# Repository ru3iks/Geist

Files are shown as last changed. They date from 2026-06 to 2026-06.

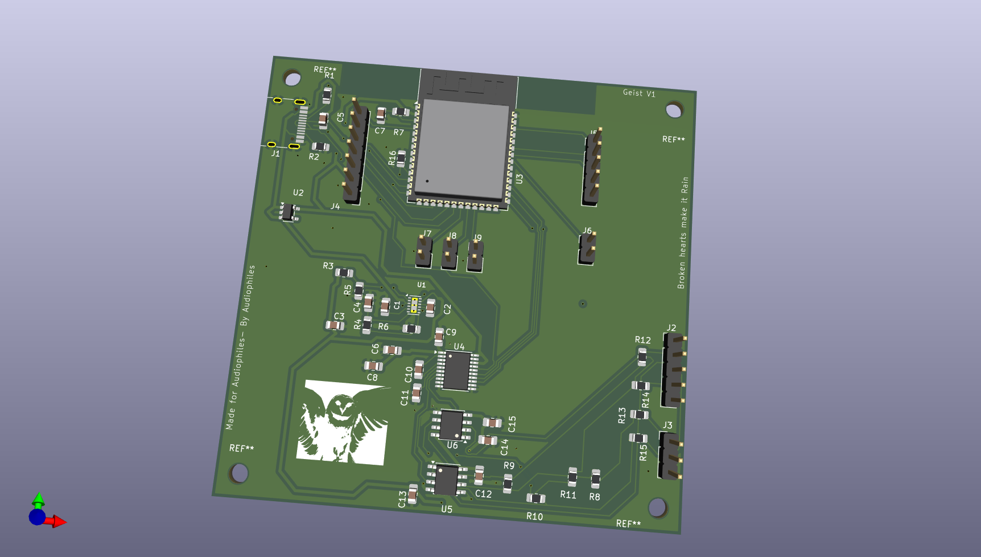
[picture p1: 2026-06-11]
Geist.png

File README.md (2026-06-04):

<div align="center">

# GEIST

**A reference-grade balanced USB DAC, real-time DSP engine, and tactile media controller — designed and built from scratch.**

`ESP32-S3` · `PCM5102A` · `OPA1656` · `Rust` · `Tauri`

---

*24-bit · 96kHz · Balanced 4.4mm Pentaconn · 10-Band Parametric EQ · FFT Visualizer*

</div>

---

## What is Geist?

Geist is an open-source USB audio device that I designed from the ground up — the circuit, the PCB, the firmware, and the companion app. It plugs into a computer over USB-C and serves three functions simultaneously:

1. **Reference-Grade USB DAC** — Enumerates as a class-compliant USB Audio device (UAC1). Receives lossless 24-bit/96kHz audio, converts it through a hardware DAC, and drives headphones through a true balanced amplifier stage.

2. **Real-Time DSP Engine** — A 10-band parametric EQ processes audio in real-time on the ESP32-S3's vector DSP unit. An FFT spectrum visualizer renders live on the onboard display.

3. **Tactile Media Controller** — Physical rotary encoder, mechanical buttons, and a toggle switch send HID commands back to the PC for volume and playback control. No drivers needed.

The companion desktop app (built in Rust + Tauri) pushes track metadata and album art to the device, provides a graphical EQ editor, and displays real-time audio analysis.

> This project was built as a 2nd year B.Tech ECE student at Manipal Institute of Technology. Every part of it — analog circuit design, mixed-signal PCB layout, embedded Rust firmware, and desktop application — was learned and implemented from scratch.

---

## Hardware Architecture

### The Signal Chain

```
  USB-C ──► AP2112K (3.3V LDO) ──► ESP32-S3 ──► PCM5102A DAC ──► 2× OPA1656 ──► Headphones
       └──► LM27762 (±4.5V Charge Pump) ─────────────────────────────┘
```

Every component was selected to serve a specific role in the audio path:

| Block | Component | Role |
|---|---|---|
| **Power (Digital)** | AP2112K-3.3 | LDO regulator — steps 5V USB to clean 3.3V for all digital logic |
| **Power (Analog)** | LM27762 | Bipolar charge pump — generates ±4.5V dual rails for the op-amps |
| **Digital Brain** | ESP32-S3-WROOM-1 | Dual-core 240MHz processor — USB audio streaming, DSP, UI control |
| **DAC** | PCM5102A | 32-bit delta-sigma DAC — converts I2S digital audio to analog |
| **Amplifiers** | 2× OPA1656 | Ultra-low-noise dual op-amps — buffers and creates balanced output |
| **Display** | ST7789 (240×240) | SPI LCD — track info or FFT visualizer |
| **Input** | Alps EC11 + 3 push buttons + SPDT toggle | Volume/nav encoder, media keys, mode switch |
| **Output** | 4.4mm Pentaconn + 3.5mm TRS | True balanced and single-ended headphone outputs |

### The Life of an Audio Sample

This table traces a single sample from the moment it leaves the PC to the moment it moves air:

```
Step   Location                  Signal State                        Domain
─────────────────────────────────────────────────────────────────────────────
 1     PC audio engine           24-bit integer: 0x3FFFFF            Software
 2     USB cable (D+/D-)         NRZI-encoded differential packet    Digital
 3     ESP32 USB DMA buffer      Bytes in RAM                        Digital
 4     ESP32 I2S peripheral      Serial bitstream at 3.072 MHz       Digital (3.3V)
 5     PCM5102A delta-sigma      1-bit stream at 6.144 MHz           Digital
 6     PCM5102A OUTL pin         +2.05V (audio + 1.55V DC bias)      Analog
 7     OPA1656 buffer output     +2.05V → OUT_L+ (hot phase)         Analog
 8     OPA1656 inverter output   −0.50V → OUT_L− (cold phase)        Analog
 9     After 10Ω resistors       +2.04V / −0.49V                     Analog
 10    Headphone driver          ΔV = 2.53V differential → sound     Acoustic
```

### Why Balanced?

A balanced signal carries audio on two wires moving in opposite directions. Any noise that couples into the cable appears equally on both wires and is cancelled by subtraction at the receiver:

```
Single-Ended:                      Balanced:
Signal ── ╱╲╱~~╲╱╲ ── +V+noise     HOT  ── ╱╲╱~~╲╱╲ ── +V+noise
Ground ── ──────── ── 0V            COLD ── ╲╱╲~~╱╲╱ ── −V+noise

Amp sees: signal + noise            Amp subtracts: (+V+noise) − (−V+noise)
→ noise passes through ✗            = 2V signal, noise cancelled ✓
```

The OPA1656 op-amps create this balanced pair — one half buffers the DAC output (positive phase), the other half inverts it (negative phase, gain = −1).

---

## PCB Design Philosophy

Geist is laid out on a **2-layer PCB** with strict attention to analog/digital noise isolation:

```
◄──── DIGITAL ZONE ──────────►│◄──────── ANALOG ZONE ──────────►

┌──────────┐  ┌──────────────┐ │  ┌───────────┐  ┌───────────┐
│ ESP32-S3 │  │ Display,     │ │  │ OPA1656×2 │  │ Audio     │
│          │  │ Encoder,     │ │  │           │  │ Jacks     │
│          │  │ Buttons      │ │  │           │  │           │
└──────────┘  └──────────────┘ │  └───────────┘  └───────────┘
                               │
                         ┌─────┴─────┐
                         │ PCM5102A  │ ← sits on the border
                         └───────────┘

Bottom layer: UNBROKEN ground copper pour — no splits.
```

### Key Layout Rules

- **Zonal Segregation** — All digital components (ESP32, display, buttons) on one side. All analog components (op-amps, output jacks) on the other. The PCM5102A sits on the boundary with its digital input pins facing left and analog outputs facing right.

- **Solid Ground Plane** — No split grounds. A single unbroken copper pour on the bottom layer allows return currents to flow directly beneath their source traces (path of least inductance), minimizing loop area and radiated noise. This is the modern best practice endorsed by TI, Analog Devices, and EMC engineers — not the outdated "split and bridge" approach.

- **Tight Decoupling** — Every bypass capacitor is placed physically touching the power pins of its parent IC. A decoupling cap 15mm away is electrically useless — the trace inductance defeats its purpose.

- **Antenna Isolation** — The ESP32's Wi-Fi/Bluetooth antenna overhangs the board edge with a keepout zone beneath it. No copper, no traces, no components under the antenna.

---

## Firmware Architecture

The firmware is written in **Rust** using the Embassy async runtime — bare-metal, no RTOS, no garbage collector.

```
geist-firmware/
├── src/
│   ├── main.rs                ← Embassy entry, spawns all tasks
│   ├── usb/
│   │   ├── descriptors.rs     ← USB composite device (UAC1 + HID + CDC)
│   │   ├── audio.rs           ← Isochronous audio reception, buffer management
│   │   ├── hid.rs             ← Media key HID reports
│   │   └── cdc.rs             ← Serial link to companion app
│   ├── audio/
│   │   ├── i2s.rs             ← I2S DMA driver for PCM5102A
│   │   ├── buffer.rs          ← Lock-free ring buffer (USB → I2S)
│   │   └── dsp.rs             ← Biquad EQ engine + FFT analysis
│   ├── ui/
│   │   ├── display.rs         ← ST7789 SPI driver
│   │   ├── encoder.rs         ← EC11 rotary encoder with debounce
│   │   ├── buttons.rs         ← Debounced media buttons
│   │   └── renderer.rs        ← Track info view + spectrum visualizer
│   └── app/
│       └── state.rs           ← Global state machine
```

### USB Composite Device

Geist enumerates as three USB interfaces simultaneously — no custom drivers required:

| Interface | USB Class | Function |
|---|---|---|
| Audio Control + Audio Streaming | UAC1 | Appears as a sound card — receives PCM audio from the OS |
| HID (Consumer Control) | HID | Sends media keys (play/pause/next/prev) and volume from the encoder |
| CDC ACM | CDC | Virtual serial port for companion app communication |

### Real-Time DSP

The 10-band parametric EQ runs as a chain of biquad filters — each band is 5 multiplies and 4 adds per sample:

```rust
// One EQ band — runs for every sample, every channel
fn process(&mut self, x: f32) -> f32 {
    let y = self.b0 * x + self.b1 * self.x1 + self.b2 * self.x2
          - self.a1 * self.y1 - self.a2 * self.y2;
    self.x2 = self.x1; self.x1 = x;
    self.y2 = self.y1; self.y1 = y;
    y
}
```

At 48kHz stereo with 10 bands, this amounts to ~5 million operations per second — less than 2% of the ESP32-S3's capacity. The biquad coefficients are computed by the companion app from human-readable parameters (frequency, gain, Q) and sent over the CDC serial link.

### Task Model

```
Core 0 (Real-time audio — never blocked):
├── usb_audio_task()       ← Isochronous USB reception
├── i2s_feed_task()        ← Drains ring buffer → I2S DMA → PCM5102A
└── usb_hid_cdc_task()     ← HID reports + serial I/O

Core 1 (UI + DSP — lower priority):
├── dsp_task()             ← Biquad EQ processing + FFT analysis
├── display_task()         ← ST7789 rendering @ 30fps
└── input_task()           ← Encoder + button polling + debounce
```

---

## Companion App

Built with **Tauri** (Rust backend + web frontend) — a ~5MB native app, not a 150MB Electron wrapper.

### Features

- **Now Playing** — Reads track info from the OS media session (Windows SMTC / macOS MediaRemote / Linux MPRIS2) and pushes title, artist, and album art to Geist's display over CDC serial
- **10-Band Parametric EQ** — Interactive frequency response curve editor. Drag bands to set frequency, gain, and Q. Coefficients are computed locally and sent to the ESP32 in real-time
- **Real-Time Visualizer** — Captures system audio via loopback and renders spectrum analyzer, waveform, and spectrogram views in the browser frontend
- **Device Dashboard** — Connection status, sample rate, firmware version, output mode
- **System Tray** — Runs silently in the background, auto-connects when Geist is plugged in
- **Firmware Update** — Flash new firmware to the ESP32 over USB without opening the case
- **Listening Stats** — Tracks hours, volume levels, and session history in a local SQLite database

### Tech Stack

| Layer | Technology |
|---|---|
| Backend | Rust (serialport, windows-rs, cpal, rustfft, rusqlite) |
| Frontend | Svelte + HTML5 Canvas for visualizations |
| Framework | Tauri v2 |
| Protocol | JSON messages + binary RGB565 art over CDC serial |

---

## Bill of Materials

| Component | Part Number | Quantity | Description |
|---|---|---|---|
| MCU | ESP32-S3-WROOM-1 | 1 | Dual-core 240MHz, USB OTG, vector DSP |
| DAC | PCM5102A (PWR) | 1 | 32-bit delta-sigma, I2S input, 112dB SNR |
| Op-Amp | OPA1656IDR | 2 | Ultra-low-noise dual op-amp, 2.8 nV/√Hz |
| LDO | AP2112K-3.3TRG1 | 1 | 3.3V, 600mA, low-dropout regulator |
| Charge Pump | LM27762DSSR | 1 | Bipolar ±output from single supply |
| USB Connector | USB-C 16-pin | 1 | PCB-mount receptacle |
| Display | ST7789 240×240 | 1 | SPI TFT LCD module |
| Encoder | Alps EC11 | 1 | Rotary encoder with push switch |
| Toggle | SPDT | 1 | Mode select switch |
| Buttons | Tactile push | 3 | Prev / Play-Pause / Next |
| Balanced Jack | 4.4mm Pentaconn | 1 | Panel-mount, 5-pole |
| SE Jack | 3.5mm TRS | 1 | Panel-mount, 3-pole |
| Resistors | 0805 | 15 | Various values (see schematic) |
| Capacitors | 0805 | 15 | 0.1µF, 2.2µF, 4.7µF, 10µF |

---

## Project Structure

```
Geist/
├── hardware/                    ← KiCad project
│   ├── Geist.kicad_pro
│   ├── Geist.kicad_sch          ← Schematic
│   ├── Geist.kicad_pcb          ← PCB layout
│   └── fabrication/             ← Gerber files for manufacturing
│
├── firmware/                    ← ESP32-S3 Rust firmware
│   ├── Cargo.toml
│   └── src/
│
├── companion/                   ← Tauri desktop app
│   ├── src-tauri/               ← Rust backend
│   ├── src/                     ← Svelte frontend
│   └── package.json
│
├── enclosure/                   ← 3D-printable case (STEP/STL)
│
├── docs/
│   ├── hardware-signal-trace.md ← Complete electrical signal walkthrough
│   └── usb-audio-architecture.md← USB Audio Class deep dive
│
└── README.md
```

---

## Design Specifications

| Parameter | Value |
|---|---|
| Audio Format | PCM, 24-bit, 48kHz / 96kHz |
| USB Class | UAC1 (class-compliant, driverless) |
| DAC SNR | 112 dB (A-weighted) |
| DAC THD+N | −93 dB |
| Amp Noise | 2.8 nV/√Hz |
| Amp THD+N | −132 dB (0.000025%) |
| Output (Balanced) | 4.4mm Pentaconn, ~4 Vrms differential |
| Output (SE) | 3.5mm TRS |
| DSP | 10-band parametric EQ (biquad IIR) |
| Visualization | 1024-point FFT, real-time spectrum |
| Power | USB bus-powered (5V, <500mA) |
| PCB | 2-layer, solid ground plane |
| Firmware | Rust + Embassy (bare-metal async) |
| Companion App | Rust + Tauri + Svelte |

---

## Building

> 🚧 Build instructions will be added as each subsystem is completed.

### Hardware
1. Open `hardware/Geist.kicad_pro` in KiCad 9.0+
2. Generate Gerbers and order from JLCPCB or PCBWay (2-layer, 1.6mm, 1oz copper)
3. Source components from LCSC/Mouser/Digikey (see BOM above)
4. Hand-solder with hot air station (TSSOP/QFN packages) and soldering iron (0805 passives, connectors)

### Firmware
```bash
# Prerequisites: Rust toolchain + ESP32 target
rustup target add xtensa-esp32s3-none-elf
cargo install espflash

# Build and flash
cd firmware
cargo build --release
espflash flash target/xtensa-esp32s3-none-elf/release/geist-firmware
```

### Companion App
```bash
# Prerequisites: Rust, Node.js 18+, pnpm
cd companion
pnpm install
pnpm tauri dev     # development
pnpm tauri build   # production binary
```

---

## License

This project is open-source under the [MIT License](LICENSE).

---

<div align="center">

Designed and built by **Arihant** · MIT Manipal · 2026

*A project born from curiosity about what sits between the music and the ear.*

</div>

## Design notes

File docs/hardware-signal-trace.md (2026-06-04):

# Geist — Hardware Signal Trace

> Every signal that enters, exits, or moves inside Geist, explained at the wire level.

---

## The Complete Signal Chain

```
                    ┌─────────────────────────────────────────────────────┐
                    │                     GEIST                           │
                    │                                                     │
    USB-C ════╦═══► │  ┌─────────┐   ┌──────────┐   ┌──────────────────┐ │
    Cable     ║     │  │ AP2112K │──►│ ESP32-S3 │──►│ PCM5102A         │ │
  (from PC)   ║     │  │  (3.3V) │   │  (Brain) │   │ (Digital→Analog) │ │
              ║     │  └─────────┘   └──────────┘   └────────┬─────────┘ │
              ║     │  ┌─────────┐                           │           │
              ║     │  │ LM27762 │                     ┌─────┴─────┐     │
              ║     │  │ (±4.5V) │────────────────────►│ 2×OPA1656 │     │ ══► Headphones
              ║     │  └─────────┘                     │  (Amps)   │     │
              ║     │                                  └───────────┘     │
              ║     └─────────────────────────────────────────────────────┘
              ║
         5V Power
       + Data (D+/D-)
```

The signal passes through **five distinct stages**. Each stage transforms the signal in a fundamentally different way. Here's what happens at every single one.

---

## Stage 1 — The USB-C Connector: Power and Data Extraction

### The Physical Connection

```
USB-C Receptacle (J1) — 16-pin PCB mount
┌──────────────────────────────────────────────────┐
│  Pin    │ Name   │ Voltage        │ Role         │
├─────────┼────────┼────────────────┼──────────────┤
│  A4/B4  │ VBUS   │ +5.0V DC       │ Power rail   │
│  A1/B1  │ GND    │ 0V (reference) │ Return path  │
│  A7     │ D-     │ 0–3.3V diff.   │ USB data (−) │
│  A6     │ D+     │ 0–3.3V diff.   │ USB data (+) │
│  A5     │ CC1    │ via 5.1kΩ→GND  │ Orientation  │
│  B5     │ CC2    │ via 5.1kΩ→GND  │ detection    │
│  Shell  │ SHIELD │ → GND          │ EMI shield   │
└──────────────────────────────────────────────────┘
```

When you plug in the cable, two things happen simultaneously:

**Power**: The host PC sources +5.0V on the VBUS pins. This is the single power source for the entire device — every voltage rail on the board is derived from this. The 5.1kΩ pull-down resistors on CC1/CC2 (R1) tell the host "I am a device that wants power" — without these resistors, a USB-C port will not turn on VBUS at all. These resistors also let the host detect which orientation the cable is plugged in.

**Data**: The D+ and D- lines carry the USB Full-Speed differential signal. "Differential" means data is encoded as the *voltage difference* between D+ and D−, not the absolute voltage on either wire. When D+ is HIGH and D- is LOW (difference > +200mV), that's a "J" state. The reverse is a "K" state. By toggling between J and K, the host and device exchange data packets at 12 million bits per second.

> The USB data lines connect directly to the ESP32-S3's internal USB OTG transceiver on GPIO19 (D−) and GPIO20 (D+). No external PHY chip is needed — the transceiver, pull-up resistors, and signal conditioning are all inside the ESP32 silicon.

### The Decoupling Capacitor (C5: 4.7µF)

Sits right at the VBUS input. When the ESP32 suddenly draws a burst of current (e.g., a USB transaction), the voltage on VBUS would dip for a few nanoseconds because the USB cable has inductance (it resists sudden changes in current). C5 acts as a local energy reservoir — it discharges instantly to fill that dip, keeping the voltage stable. Think of it as a tiny battery that only activates during microsecond-scale demand spikes.

---

## Stage 2 — Power Delivery: One Source, Two Worlds

The +5V from USB splits into two completely independent supply rails — one for digital logic, one for analog audio. These two rails are designed to be electrically isolated from each other so that the digital noise from the ESP32 never contaminates the analog audio signal.

### The Digital Rail: AP2112K-3.3 (U2)

```
            AP2112K-3.3
            ┌──────────┐
  +5.0V ───►│ VIN  VOUT├───► +3.3V (Digital)
            │          │       │
  R7:10k ──►│ EN   GND ├───┐  ├── C6: 2.2µF (output stability)
            └──────────┘   │  │
                          GND GND
```

The AP2112K is a **Low-Dropout Regulator (LDO)**. It takes the 5V input and outputs a rock-stable 3.3V by continuously adjusting an internal pass transistor — essentially a variable resistor that burns the excess 1.7V as heat. The "low-dropout" part means it can regulate even when the input voltage sags close to the output (it only needs ~250mV of headroom).

**What does it power?**
- The ESP32-S3's core logic (CPU, memory, I2S peripheral)
- The ST7789 display controller
- The rotary encoder and button pull-ups
- The PCM5102A's *digital* supply pins (DVDD, CPVDD)

**C6 (2.2µF)**: The output capacitor. Every LDO requires one for stability — it's part of the feedback loop. Without it, the LDO's internal control loop oscillates and the output becomes a mess of high-frequency ringing instead of a clean DC rail. The 2.2µF value is specified in the AP2112K datasheet as the minimum for stable operation.

**R7 (10kΩ)**: The enable pull-up. Ties the EN pin high through VBUS so the LDO turns on as soon as USB power appears.

### The Analog Rail: LM27762 (U1)

This is the more interesting one. The OPA1656 op-amps need **both a positive and negative supply** to swing an audio waveform above and below 0V. USB only gives you +5V. The LM27762 solves this by generating both **+4.5V and −4.5V** from the single +5V input.

```
                        LM27762
                   ┌──────────────┐
  +5.0V ──────────►│ VIN    OUT+  ├──────────────────────────► +4.5V_Audio
                   │              │   │
  R3: 27.4kΩ ────►│ FB+     EN+  │   ├── C3: 2.2µF (positive output cap)
  R4: 26.7kΩ ────►│ FB-     EN-  │   ├── C12: 0.1µF (HF decoupling)
                   │              │
         C1 ──────│ C+      OUT- ├──────────────────────────► -4.5V_Audio
  (4.7µF)         │              │   │
         C2 ──────│ C-       CP  │   ├── C4: 2.2µF (negative output cap)
  (4.7µF)         │              │   ├── C14: 0.1µF (HF decoupling)
                   │         GND │
                   └──────┬──────┘
                          │
                         GND
```

**How the charge pump actually works:**

The LM27762 contains a set of internal switches and uses **C1 (the "flying capacitor")** as an energy shuttle. Here's the two-phase cycle, which repeats ~1 million times per second:

```
Phase 1 — CHARGE:                    Phase 2 — TRANSFER:

  +5V ──┐                             +5V     (disconnected)
        ├── Switch closes                    
        │                                    Switch closes
   ┌────┴────┐                         ┌────────┐
   │ C1      │  ← Charges to ~4.5V     │ C1     │  ← Dumps charge
   │ (flying)│                         │(flying)│     into C4
   └────┬────┘                         └────┬───┘
        │                                   │
        ├── Switch closes to GND            ├── Switch connects to OUT-
       GND                                  │
                                       ┌────┴────┐
                                       │ C4      │  ← Builds up
                                       │ (output)│     negative voltage
                                       └────┬────┘
                                            │
                                          -4.5V
```

In Phase 1, C1 charges to the positive output voltage (~4.5V) with its top plate connected to VIN and its bottom plate to GND. In Phase 2, the switches flip — the *top* plate of C1 is connected to GND and the *bottom* plate to the negative output. Since C1 is still holding its charge, the bottom plate is now forced to sit at approximately −4.5V relative to ground. This charge is dumped into C4, the negative output capacitor.

The positive output (+4.5V) is generated by a separate internal LDO from VIN, with the feedback resistor R3 (27.4kΩ) setting the exact voltage.

**The feedback resistors R3/R4**: These set the output voltages via a resistor divider. The LM27762's internal reference compares the divided output to a fixed 1.2V bandgap reference and adjusts the regulation to maintain the target voltage. With the values you've chosen (27.4kΩ and 26.7kΩ), the positive rail lands at approximately +4.5V.

**What does ±4.5V power?**
- Only the OPA1656 op-amps. Nothing else. This rail exists solely to give the op-amps enough voltage swing to drive headphones with a clean, undistorted waveform.

**The 0.1µF capacitors (C12, C13, C14, C15)**: High-frequency decoupling. The 2.2µF electrolytic/ceramic output caps handle bulk energy storage, but they're too physically large (internally) to respond to very fast transients. The 0.1µF ceramics have extremely low ESR (effective series resistance) and can absorb high-frequency noise spikes in the 1–100 MHz range — exactly where the charge pump's switching harmonics live.

> **Why ±4.5V and not ±5V?** Headroom. The LM27762 has internal dropout, so it can't output the full input voltage. Additionally, keeping the rails slightly below 5V gives the op-amps thermal margin and keeps them well within their rated supply range (max ±9V for the OPA1656).

---

## Stage 3 — The Digital Brain: ESP32-S3

The ESP32-S3 is where data becomes audio-shaped. But it does no analog processing — everything here is pure digital math on binary numbers.

### What Happens Inside (Electrically)

```
USB D+/D- ──► USB OTG          I2S Peripheral ──► I2S_BCLK  (GPIO21)
              Peripheral              │        ──► I2S_LRCK  (GPIO35)
                  │                   │        ──► I2S_DATA  (GPIO36)
                  │            ┌──────┘
                  ▼            │
           ┌─────────────┐    │
           │  DMA Engine  │───┘   (Direct Memory Access — moves data
           │              │        without CPU intervention)
           └──────┬───────┘
                  │
           ┌──────▼──────┐
           │ Dual Xtensa │    240 MHz, vector instructions
           │   LX7 CPU   │    for FFT/DSP processing
           └─────────────┘
```

1. **USB packets arrive** as isochronous transfers — 288 bytes every 1ms (at 48kHz/24-bit stereo). The USB peripheral's DMA engine writes these directly into a RAM buffer without the CPU lifting a finger.

2. **The CPU reads these samples** and places them into the I2S peripheral's transmit DMA buffer. Again, DMA handles the actual byte-shuffling — the CPU just manages the pointers.

3. **The I2S peripheral outputs three signals**, continuously, at a precise clock rate:

### The I2S Bus — Three Wires, One Audio Stream

```
I2S_BCLK (Bit Clock)     ──── 48kHz × 2ch × 32bits = 3.072 MHz square wave
                                ┌─┐ ┌─┐ ┌─┐ ┌─┐ ┌─┐ ┌─┐ ┌─┐ ┌─┐
                               ─┘ └─┘ └─┘ └─┘ └─┘ └─┘ └─┘ └─┘ └─┘

I2S_LRCK (L/R Clock)     ──── 48 kHz, tells the DAC which channel is active
                               ┌───────────────────┐
                          LEFT ─┘                   └───────────────────
                                                     RIGHT

I2S_DATA                  ──── Serial bitstream, MSB first
                                Each sample: 24 data bits + 8 padding bits
                               ┌─Bit23─┬─Bit22─┬─Bit21─┬─ ... ─┬─Bit0─┬─pad─┐
                               │  MSB  │       │       │       │ LSB  │ 0s  │
```

**BCLK** (Bit Clock): A continuous 3.072 MHz square wave. Each rising edge means "read the next bit from the DATA line." This clock is generated by the ESP32's I2S peripheral, derived from its internal PLL. Every edge of this clock matters — if an edge arrives even a few nanoseconds early or late (jitter), the DAC will reconstruct a slightly wrong voltage, manifesting as a faint hiss or distortion. This is why I2S clock quality is critical in audio design.

**LRCK** (Left/Right Clock): A 48 kHz square wave (= sample rate). When HIGH, the data on I2S_DATA belongs to the Left channel. When LOW, it's the Right channel. This clock defines the sample rate. The DAC uses this edge as its trigger to latch a complete sample and begin conversion.

**DATA**: A serial bitstream. Each audio sample is 24 bits sent MSB-first (most significant bit first), packed into a 32-bit I2S word slot. The extra 8 bits are zero-padded. At 48kHz stereo, the DATA line carries 48,000 × 2 × 32 = 3,072,000 bits per second — exactly synchronized to BCLK.

> These three wires are the boundary between the digital and analog worlds. Everything before this point is square-wave logic. Everything after this point is continuous voltage.

---

## Stage 4 — The DAC: PCM5102A (U4)

The PCM5102A is where numbers become sound. It takes the 24-bit integers from the I2S bus and outputs a proportional analog voltage.

### Pin-Level Connections

```
                         PCM5102A (U4)
                    ┌────────────────────┐
  I2S_LRCK  ──────►│ LRCK    OUTL (6) ──├────────────► DAC_LEFT
  I2S_DATA  ──────►│ DIN     OUTR (7) ──├────────────► DAC_RIGHT
  I2S_BCLK  ──────►│ BCK               │
       GND  ──────►│ SCK     CPVDD (20)├──── 3.3V + C8: 0.1µF
                   │                    │
      3.3V  ──────►│ FLT     DVDD      ├──── 3.3V
      3.3V  ──────►│ DEMP    AVDD (8)  ├──── internally regulated
      3.3V  ──────►│ XSMT              │
       GND  ──────►│ FMT     CAPP (2)  ├──── C10: 2.2µF
                   │         CAPM (4)  ├──── C11: 2.2µF
                   │         VNEG (9)  ├──── (internal negative rail)
                   │         LDOO (18) ├──── (internal regulator out)
                   └────────────────────┘

  Config pins (active during power-up, latched permanently):
    FLT  = HIGH → Normal latency filter (linear phase)
    DEMP = HIGH → De-emphasis OFF
    XSMT = HIGH → Soft mute OFF (output active)
    FMT  = LOW  → Standard I2S format
    SCK  = GND  → Use internal PLL (derive system clock from BCK)
```

### What Happens Inside the DAC

The PCM5102A is a **delta-sigma DAC**. This is not a simple R-2R ladder — it's a fundamentally different architecture that trades speed for precision:

```
24-bit      ┌──────────────┐    ┌──────────┐    ┌──────────────┐
samples ───►│ Interpolation│───►│ Delta-   │───►│ Analog       │───► OUTL/OUTR
(48kHz)     │ Filter       │    │ Sigma    │    │ Reconstruction│    (analog)
            │              │    │ Modulator│    │ Filter        │
            │ Upsamples to │    │          │    │               │
            │ ~6.144 MHz   │    │ 1-bit    │    │ Smooths the   │
            │ (128× over-  │    │ stream   │    │ 1-bit stream  │
            │  sampling)   │    │ at very  │    │ into a clean  │
            │              │    │ high rate│    │ continuous     │
            └──────────────┘    └──────────┘    │ waveform      │
                                                └──────────────┘
```

**Step 1 — Interpolation (Digital Oversampling)**: The incoming 48,000 samples/second stream is digitally upsampled to ~6.144 million samples/second (128× oversampling). This is done by inserting zeros between original samples and then applying a digital lowpass filter. The purpose is to push the quantization noise far above the audible frequency range (20 kHz).

**Step 2 — Delta-Sigma Modulation**: The upsampled stream is converted to a 1-bit bitstream running at 6.144 MHz. Instead of each sample being a 24-bit number, each sample is just 0 or 1, but switching incredibly fast. Through noise shaping, the modulator pushes quantization errors to ultrasonic frequencies where they're inaudible. This is the core trick of delta-sigma — you trade bit depth for speed.

**Step 3 — Analog Reconstruction Filter**: A simple analog lowpass filter smooths the rapid 1-bit switching into a continuous voltage waveform. Because the quantization noise was pushed far above 20 kHz by the modulator, a gentle filter slope is enough to remove it cleanly without affecting the audible signal.

### The Output

The OUTL and OUTR pins output a **single-ended analog voltage** centered at roughly half the internal analog supply (~1.55V DC bias), with the audio signal swinging above and below that bias point:

```
Voltage at OUTL pin (playing a sine wave):

  ~2.65V  ─ ─ ─╲─ ─ ─ ─ ─ ─ ─ ─╲─ ─ ─ ─ ─ ─     peak
               ╱ ╲             ╱ ╲
              ╱   ╲           ╱   ╲
  ~1.55V ───╱─────╲─────────╱─────╲──────────     DC bias (quiescent)
           ╱       ╲       ╱       ╲
          ╱         ╲     ╱         ╲
  ~0.45V ╱───────────╲───╱───────────╲────────     trough
                      ╲╱

  Full-scale output: ~2.1 Vrms (specified in the datasheet)
```

This signal has three properties:
1. It rides on a **DC offset** (~1.55V) — this bias must be removed before it reaches headphones, or it would push the driver cone to one side permanently and waste power as heat.
2. It's **single-ended** — referenced to ground. The signal voltage moves, ground stays at 0V.
3. It's relatively **high-impedance** — the PCM5102A's output stage can't drive a headphone directly with any authority. It needs a buffer.

This is where the op-amps come in.

### The Internal Charge Pump (CAPP/CAPM/VNEG)

The PCM5102A has its own tiny charge pump inside, separate from the LM27762. The external capacitors on CAPP (C10: 2.2µF) and CAPM (C11: 2.2µF) are the flying and output capacitors for this internal pump. It generates a negative voltage (VNEG) that powers the DAC's internal analog output stage, giving it enough voltage swing to reach the full ±2.1 Vrms output.

> This is why the PCM5102A datasheet says you don't need a negative supply externally — it makes its own. But its output stage is weak (high impedance), which is why you still need the external OPA1656 op-amps to drive headphones.

---

## Stage 5 — The Amplifiers: OPA1656 (U5, U6)

The OPA1656 is a dual op-amp — two independent amplifiers in one 8-pin package. Geist uses **two packages** (four total op-amp halves), configured to produce a **true balanced output** for each stereo channel.

### What "Balanced" Means Electrically

A single-ended signal has one wire that moves (signal) and one wire that stays still (ground). A balanced signal has **two wires that both move, in opposite directions**:

```
Single-Ended (3.5mm):                Balanced (4.4mm Pentaconn):

  Signal ──── ╱╲╱╲╱╲ ──── +V          HOT  (L+) ──── ╱╲╱╲╱╲ ──── +V
  Ground ──── ──────── ──── 0V         COLD (L-) ──── ╲╱╲╱╲╱ ──── -V  (inverted!)
                                       Ground    ──── ──────── ──── 0V

  If noise couples into the cable:     If the SAME noise couples in:

  Signal ──── ╱╲╱~~╲╱╲ ── +V+noise    HOT  ──── ╱╲╱~~╲╱╲ ──── +V+noise
  Ground ──── ──────── ──── 0V         COLD ──── ╲╱╲~~╱╲╱ ──── -V+noise
                                       
  Amplifier sees: signal + noise       Amp subtracts: (HOT) - (COLD)
  → noise passes through ✗             = (+V+noise) - (-V+noise)
                                       = 2V  ← signal DOUBLED
                                       noise CANCELLED ✓
```

The receiver (your headphone amp, or the amplifier in balanced IEMs) subtracts COLD from HOT. Any noise that coupled equally into both wires (called "common-mode" noise) gets subtracted to zero. The signal, being opposite in polarity on each wire, gets *doubled*. This is why balanced connections have higher output voltage and better noise rejection.

### The Op-Amp Topology (Per Channel)

Each channel uses one OPA1656 package. One half buffers the DAC output (positive/hot phase). The other half inverts it (negative/cold phase):

```
                        ┌──── +4.5V_Audio (V+)
                        │
   DAC_LEFT ────────────┤
   (from PCM5102A       │       U5A: Unity-Gain Buffer
    OUTL pin)           │       (Non-Inverting, Gain = +1)
                        │
                        │         ┌─────────┐
                        ├────────►│ +       │
                        │         │  U5A    ├─────┬──────► OUT_L+  (Hot)
                        │    ┌───►│ -       │     │
                        │    │    └─────────┘     │
                        │    │                    │
                        │    └────────────────────┘  ← 100% negative feedback
                        │                               (output wired to inverting input)
                        │
                        │
                        │       U5B: Inverting Amplifier
                        │       (Gain = -1)
                        │
                        │    R8: 10kΩ (input)
                        ├────┤►──────────┐
                        │                │
                        │         ┌──────▼──┐
                        │    ┌───►│ -       │
                        │    │    │  U5B    ├─────┬──────► OUT_L-  (Cold)
                        │    │    │ +       │     │
                        │    │    └──┬──────┘     │
                        │    │       │            │
                        │    │      GND           │
                        │    │                    │
                        │    └────────┤►──────────┘
                        │         R8: 10kΩ (feedback)
                        │
                        └──── -4.5V_Audio (V-)
```

**U5A — The Buffer (Non-Inverting, Gain = +1)**:
The DAC output connects to the non-inverting (+) input. The output is wired directly back to the inverting (−) input — this is 100% negative feedback, which forces the output to exactly follow the input. Gain = 1. The signal is not amplified; it's **buffered**.

*Why buffer if the gain is 1?* Because the OPA1656's output can deliver far more current than the PCM5102A's output pin. The DAC's output is high-impedance (~1kΩ source impedance) — it can barely push a few milliamps. The OPA1656's output impedance is a fraction of an ohm and can drive ~40mA. Headphones need current, especially low-impedance IEMs. The buffer provides that current without loading the DAC.

**U5B — The Inverter (Gain = −1)**:
This takes the same DAC signal and creates a phase-inverted copy. Two equal resistors (both R8: 10kΩ) form a classic inverting amplifier. The gain is −R_feedback / R_input = −10k/10k = **−1**. The output is the exact mirror image of the input — when U5A outputs +0.5V, U5B outputs −0.5V.

The non-inverting (+) input of U5B is tied to GND. This sets the DC operating point at 0V — the op-amp inverts around ground. This also means **the DC bias from the DAC output (~1.55V) is removed** by this stage. The inverting amplifier's virtual ground at the (−) input naturally rejects DC offset. For U5A (the buffer), you'd typically use a DC-blocking capacitor on the output to remove the bias before reaching the headphone. 

> **The ±4.5V supply rails** are why the LM27762 charge pump exists. If the op-amps only had a positive supply (say, +5V and GND), the output could only swing from ~0V to ~3.5V — it would clip the negative half of the audio waveform. With ±4.5V rails, the output can swing from roughly −3.8V to +3.8V (accounting for ~0.7V headroom to each rail), giving a clean, symmetrical waveform with no clipping.

### Why the OPA1656 Specifically?

The OPA1656 is characterised by:

| Parameter | Value | Why It Matters |
|---|---|---|
| Input noise voltage | 2.8 nV/√Hz | Exceptionally quiet — below the noise floor of the PCM5102A itself. The amp won't add audible hiss. |
| THD+N | 0.000025% (−132 dB) | Distortion is ~50 dB below what human ears can detect. The amp is transparent. |
| GBW (Gain-Bandwidth) | 28 MHz | Can accurately track signals up to hundreds of kHz — massively overqualified for 20kHz audio, which ensures zero phase distortion in the audible band. |
| Output current | ±40 mA | Enough to drive low-impedance IEMs (like your Titan S2 at 12Ω) to deafening levels. |
| Supply range | ±2.25V to ±18V | Comfortable at ±4.5V with plenty of margin. |

---

## Stage 6 — The Output Jacks

### The 10Ω Series Resistors (R12, R13, R14, R15)

Before the signals reach the jacks, each line passes through a 10Ω resistor:

```
  OUT_L+  ───┤ R12: 10Ω ├──── pin on J2 (4.4mm Pentaconn)
  OUT_L-  ───┤ R13: 10Ω ├──── pin on J2
  OUT_R+  ───┤ R14: 10Ω ├──── pin on J2
  OUT_R-  ───┤ R15: 10Ω ├──── pin on J2
```

These resistors serve two purposes:

1. **Short-circuit protection**: If the headphone plug is inserted or removed while the amp is live, the tip momentarily shorts to the sleeve (ground). Without series resistance, the op-amp's output would be forced directly to ground — essentially driving into 0Ω. The OPA1656 would current-limit internally but could still experience thermal stress. The 10Ω resistor limits the short-circuit current to 4.5V / 10Ω = 450mA, well within safe bounds.

2. **Cable capacitance isolation**: Headphone cables are coaxial wires — they have capacitance (~100–500pF for a 1.2m cable). A capacitive load on an op-amp output can cause the feedback loop to become unstable and oscillate at ultrasonic frequencies. The 10Ω resistor decouples the cable capacitance from the op-amp's feedback loop, preventing oscillation.

> At 10Ω, the power loss is negligible. Driving 12Ω IEMs, the 10Ω resistor adds ~45% to the source impedance, which could slightly affect the IEM's frequency response (damping factor). If you find the bass getting loose, you could lower these to 4.7Ω. For 32Ω+ headphones, 10Ω is perfect.

### The 4.4mm Pentaconn Balanced Jack (J2)

```
  J2 — 4.4mm Pentaconn (5-pole)
  ┌───────────────────────────┐
  │  Tip     → L+  (Left hot) │
  │  Ring 1  → L-  (Left cold)│
  │  Ring 2  → R+  (Right hot) │
  │  Ring 3  → R-  (Right cold)│
  │  Sleeve  → GND            │
  └───────────────────────────┘
```

The headphone's balanced amplifier (or balanced IEM cable) receives L+ and L−, subtracts them, and drives the transducer with the resulting doubled, noise-free signal.

### The 3.5mm Single-Ended Jack (J3)

```
  J3 — 3.5mm TRS (3-pole)
  ┌──────────────────────────────┐
  │  Tip    → Left signal        │ ← from OUT_L+ (or DAC_LEFT direct)
  │  Ring   → Right signal       │ ← from OUT_R+ (or DAC_RIGHT direct)
  │  Sleeve → GND                │
  └──────────────────────────────┘
```

For single-ended output, only the positive phase (the buffered, non-inverted signal) is used. The cold/inverted phase is left unconnected for this jack.

> **Design consideration**: If you're tapping the buffered output (OUT_L+, OUT_R+) for the 3.5mm jack, be aware it still carries the DAC's DC bias (~1.55V). You'll need **DC-blocking capacitors** in the signal path to the 3.5mm jack — otherwise you'd push DC current through the headphone driver. A 100µF or 220µF electrolytic in series with each signal line would work. The capacitor forms a high-pass filter with the headphone impedance, with a cutoff frequency well below 20Hz (220µF into 12Ω = fc ≈ 60Hz — you may want to go larger, or use the approach below).

> Alternatively, a more elegant solution: **AC-couple at the DAC output** before the op-amp stage, so the op-amps operate around a 0V DC bias from the start. This means both the balanced and single-ended outputs would be DC-free without extra components at the jacks.

---

## The Complete Voltage Journey — One Audio Sample

Here is the life of a single audio sample — say, a 24-bit value representing a +0.5V peak in a sine wave on the left channel:

```
Step  │ Location             │ Voltage / Data                │ Domain
──────┼──────────────────────┼───────────────────────────────┼────────
  1   │ PC audio engine      │ 0x3FFFFF (integer, ≈ +0.5V   │ Software
      │                      │  at full-scale = 2.1Vrms)     │
  2   │ USB cable (D+/D-)    │ NRZI-encoded differential     │ Digital
      │                      │ bit pattern in isoch. packet   │
  3   │ ESP32 USB DMA buffer │ 0x3FFFFF in RAM at address    │ Digital
      │                      │ 0x3FC8_XXXX                    │
  4   │ ESP32 I2S DMA output │ Serial bits on I2S_DATA wire  │ Digital
      │                      │ 0011 1111 1111 1111 1111 1111 │ (3.3V logic)
  5   │ PCM5102A internal    │ Delta-sigma bitstream: a      │ Digital
      │                      │ rapid 1/0 pattern at 6.144MHz │
  6   │ PCM5102A OUTL pin    │ +2.05V (on 1.55V bias)        │ Analog
      │                      │ = +0.5V audio + 1.55V DC      │
  7   │ OPA1656 U5A output   │ +2.05V → OUT_L+ (hot)         │ Analog
      │ (buffer)             │                               │
  8   │ OPA1656 U5B output   │ -0.50V → OUT_L- (cold)        │ Analog
      │ (inverter)           │ (DC bias rejected by          │
      │                      │  virtual ground topology)      │
  9   │ After R12/R13 (10Ω)  │ +2.04V / -0.49V              │ Analog
      │                      │ (tiny drop across resistor)    │
  10  │ Headphone driver     │ ΔV = (+2.04) − (−0.49)        │ Acoustic
      │ (balanced IEM)       │    = 2.53V differential       │  → sound
      │                      │ → driver cone moves,          │
      │                      │   compresses air, you hear it │
```

---

## Noise Isolation Strategy — Why the Layout Matters

Everything described above only works cleanly if the PCB layout respects the electrical boundaries between digital and analog:

```
  ◄──────── DIGITAL ZONE ────────►│◄──────── ANALOG ZONE ────────►
                                  │
  ┌──────────┐  ┌──────────────┐  │  ┌───────────┐  ┌───────────┐
  │ ESP32-S3 │  │ Buttons,     │  │  │ OPA1656×2 │  │ Audio     │
  │ (U3)     │  │ Encoder,     │  │  │ (U5, U6)  │  │ Jacks     │
  │          │  │ Display      │  │  │           │  │ (J2, J3)  │
  └──────────┘  └──────────────┘  │  └───────────┘  └───────────┘
         │                        │         ▲
         │        I2S bus         │         │
         └────────────────────────┼─────────┘
                                  │
                            ┌─────┴─────┐
                            │ PCM5102A  │  ← sits on the border
                            │ (U4)      │     digital input side faces left,
                            └───────────┘     analog output side faces right

  Bottom layer: UNBROKEN ground copper pour across the entire board.
  No splits, no cuts, no traces on the ground plane.
```

**Why no split ground?** A common myth says you should split the ground into "digital ground" and "analog ground." In reality, a split forces return currents to take long, indirect paths around the gap — creating exactly the ground loop antenna you were trying to avoid. A **solid, unbroken ground plane** allows every return current to flow directly underneath its source trace (the path of least inductance), minimising loop area and therefore minimising radiated and received noise.

**Why zonal segregation on the top layer?** The noise coupling you're fighting isn't through the ground — it's through **electromagnetic radiation** from digital traces and **capacitive coupling** between adjacent traces. By keeping all high-speed switching (ESP32's 240MHz clock, SPI bus, USB) physically far from the sensitive analog traces (DAC output, op-amp inputs), you reduce the field strength at the analog traces to negligible levels. Distance is your most effective shield.

**Why tight decoupling?** Every IC has parasitic inductance in its power pins (the bond wires and package leads). When the IC switches states, it demands a spike of current through these inductors, causing a brief voltage drop (Ldi/dt). The 0.1µF ceramic capacitors placed *touching* the IC's power pins provide that current spike locally, so the disturbance doesn't propagate down the power trace to contaminate other ICs.

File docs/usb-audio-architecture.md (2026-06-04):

# USB Audio Deep Dive — Geist Edition

> [!NOTE]
> This document explains USB Audio Class 1.0 from the ground up, specifically in the context of Geist's hardware. Every concept is tied to your actual signal chain. Keep this as a reference when you start writing firmware.

---

## 1. The Big Picture: What Happens When You Plug Geist In

When you plug Geist's USB-C cable into your PC, the following happens in roughly 200ms:

1. The PC's USB host controller detects a device (pull-up resistor on D+)
2. The PC asks: **"What are you?"** — it reads your **Device Descriptor**
3. The PC asks: **"What can you do?"** — it reads your **Configuration Descriptor** (which contains all your interfaces)
4. The PC sees three things inside:
   - "I'm a sound card" → **Audio Class interface** → loads the built-in USB Audio driver
   - "I have media keys" → **HID interface** → loads the built-in HID driver  
   - "I have a serial port" → **CDC interface** → loads the built-in serial driver
5. The PC activates the configuration, and Geist is live — no custom drivers needed

This is what "class-compliant" means. The OS already has drivers for Audio, HID, and CDC. You just need to describe yourself correctly through **descriptors**.

---

## 2. The USB Descriptor Hierarchy

Think of descriptors as a nested data structure — a tree. The host reads the whole tree to understand your device. Here's Geist's complete tree:

```
Device Descriptor (1 device = Geist)
│
└── Configuration Descriptor (1 configuration)
    │
    ├── IAD (Interface Association Descriptor) ─── groups Audio interfaces
    │   │
    │   ├── Interface 0: Audio Control (AC)
    │   │   └── AC Header
    │   │   └── Input Terminal  (USB streaming in)
    │   │   └── Feature Unit    (volume control)
    │   │   └── Output Terminal (speaker/DAC out)
    │   │
    │   └── Interface 1: Audio Streaming (AS)
    │       ├── Alt Setting 0: Zero-bandwidth (idle — no endpoint)
    │       └── Alt Setting 1: Active streaming
    │           └── AS Header (links to Input Terminal)
    │           └── Format Descriptor (PCM, 24-bit, 48/96kHz, stereo)
    │           └── Isochronous Endpoint (the actual data pipe)
    │           └── Audio Endpoint descriptor (sample rate control)
    │
    ├── Interface 2: HID (media keys + volume knob)
    │   └── HID Descriptor
    │   └── Interrupt Endpoint IN (sends key events to PC)
    │
    └── Interface 3: CDC ACM (serial port for companion app)
        ├── CDC Control Interface
        │   └── Interrupt Endpoint IN (serial state notifications)
        └── CDC Data Interface
            ├── Bulk Endpoint IN  (data FROM Geist to PC)
            └── Bulk Endpoint OUT (data FROM PC to Geist)
```

Each of these is a packed binary struct that you define in your firmware. When the host reads the Configuration Descriptor, it gets **all** of this in one big blob. Let's break down each piece.

---

## 3. USB Audio Class 1.0 — The Sound Card

### 3.1 Why UAC1 and not UAC2?

| | UAC1 | UAC2 |
|---|---|---|
| Designed for | Full-Speed (12 Mbps) ✓ | High-Speed (480 Mbps) |
| Max practical quality | 24-bit / 96 kHz ✓ | 32-bit / 384 kHz |
| Windows driver | Built-in since XP | Built-in since Win10 1703 |
| macOS driver | Built-in since 10.2 | Built-in since 10.6 |
| Linux driver | Built-in since 2.4 | Built-in since 2.6 |
| Implementation complexity | Simpler | More complex (clock domains, feedback) |

Since the ESP32-S3 is Full-Speed only and you want plug-and-play on every machine, **UAC1 is the correct choice**. UAC2 would buy you nothing and risk Windows compatibility issues.

### 3.2 The Audio Control (AC) Interface — Your "Topology"

The AC interface doesn't carry audio data. It describes the **signal path** inside your device as a graph of **Terminals** and **Units**. The host reads this to understand what your device can do (adjust volume? select inputs? mute?).

Here's what Geist's topology looks like:

```
                        ┌──────────────────────────────────┐
                        │     Audio Control Interface      │
                        │         (Interface 0)            │
                        │                                  │
  USB audio data ──►    │  ┌──────────────┐                │
  from the PC           │  │ Input        │  ID = 1        │
                        │  │ Terminal     │  Type: USB      │
                        │  │ (USB Stream) │  Streaming      │
                        │  └──────┬───────┘                │
                        │         │                        │
                        │         ▼                        │
                        │  ┌──────────────┐                │
                        │  │ Feature      │  ID = 2        │
                        │  │ Unit         │  Controls:      │
                        │  │ (Volume/Mute)│  - Master Vol   │
                        │  │              │  - Mute         │
                        │  └──────┬───────┘                │
                        │         │                        │
                        │         ▼                        │
                        │  ┌──────────────┐                │
                        │  │ Output       │  ID = 3        │     ──► to I2S
                        │  │ Terminal     │  Type:          │     ──► to PCM5102A
                        │  │ (Speaker)    │  Speaker        │     ──► to OPA1656
                        │  └──────────────┘                │     ──► to your ears
                        │                                  │
                        └──────────────────────────────────┘
```

Each block is a **descriptor struct** you define in firmware:

- **Input Terminal (ID=1)**: "I receive audio from the USB host." Terminal type = `USB Streaming (0x0101)`. 2 channels (L+R).
- **Feature Unit (ID=2)**: "I can adjust volume and mute." Source = Terminal 1. This is what makes the OS volume slider work with your device. When you drag the slider, the OS sends a `SET_CUR` control request to this unit.
- **Output Terminal (ID=3)**: "Audio comes out of a speaker." Terminal type = `Speaker (0x0301)`. Source = Unit 2. In reality, "speaker" here means your DAC+amp chain — the OS doesn't care about the actual hardware.

> [!IMPORTANT]
> The Feature Unit is what makes Windows/macOS show a volume slider for Geist in Sound Settings. Without it, the OS can only do volume in software (lower bit depth). With it, your firmware receives the volume level and you can control the PCM5102A's soft mute (via XSMT GPIO) or apply digital gain before sending to I2S.

### 3.3 The Audio Streaming (AS) Interface — The Data Pipe

The AS interface is where actual PCM audio bytes flow. It has **two alternate settings**:

**Alt Setting 0 (Zero-Bandwidth):**
- No endpoint defined
- No USB bandwidth reserved
- This is the "idle" state — Geist is plugged in but no app is playing audio
- The host selects this when audio stops

**Alt Setting 1 (Active Streaming):**
- Contains an **isochronous OUT endpoint** (data flows FROM host TO device)
- USB bandwidth is reserved
- The host selects this when audio playback begins

The Format Descriptor inside Alt Setting 1 tells the host exactly what you accept:

```
Format: PCM (raw samples, no compression)
Channels: 2 (stereo)
Bit Depth: 24
Sample Rates: 48000, 96000 (you list which ones you support)
```

> [!TIP]
> You can list multiple sample rates (48kHz AND 96kHz). The OS will negotiate the best one. Most music is 44.1/48kHz; hi-res files are 96kHz. Supporting both covers everything you'd realistically play.

### 3.4 Isochronous Transfers — How Audio Actually Moves

Regular USB transfers (bulk, control) are **reliable but not real-time** — they retry on errors, which means unpredictable latency. Audio can't tolerate that. Instead, USB Audio uses **isochronous transfers**:

- The host sends one packet **every 1ms** (the USB frame period)
- Each packet contains exactly the right number of samples for that 1ms window
- **No retries, no handshakes, no ACKs** — if a packet is corrupted, it's gone
- This guarantees consistent timing at the cost of potential (rare) data loss

For 24-bit stereo at 48 kHz:
```
Samples per 1ms frame = 48,000 / 1,000 = 48 samples
Bytes per sample = 3 bytes (24-bit) × 2 channels = 6 bytes
Bytes per frame = 48 × 6 = 288 bytes   ← well within the 1,023 byte limit
```

For 24-bit stereo at 96 kHz:
```
Samples per 1ms frame = 96 samples
Bytes per frame = 96 × 6 = 576 bytes   ← still fine
```

Your firmware's job: every 1ms, the ESP32-S3's USB peripheral receives a 288-byte (or 576-byte) isochronous packet into a DMA buffer. You feed those samples into the I2S peripheral's DMA buffer for output to the PCM5102A. The critical firmware challenge is managing the **ring buffer** between these two asynchronous clocks (USB frame clock vs. I2S bit clock).

### 3.5 The Clock Synchronization Problem

This is subtle but important. Two clocks are at play:

1. **The USB host's 1ms frame clock** — driven by the PC's USB controller crystal
2. **The ESP32's I2S bit clock** — derived from the ESP32's 40MHz crystal via PLL

These two crystals are **not synchronized**. They'll run at very slightly different rates (±50 ppm typical). Over minutes, one clock will drift ahead of the other. If the host sends samples slightly faster than you consume them, your buffer will overflow. Slightly slower, and it will underflow (causing audio glitches/clicks).

**UAC1's solution: Adaptive Sync.** You declare your isochronous endpoint as "adaptive" — meaning your device adjusts its playback clock to match the host's rate. The ESP32 can do this by monitoring the buffer fill level and nudging its I2S clock divider. This is the simplest approach and is what most USB DACs use.

```
Endpoint synchronization type: Adaptive (0b01 in bmAttributes)
```

> [!NOTE]
> The alternative is "asynchronous" mode where YOUR device is the clock master and you send feedback packets telling the host to speed up or slow down. This gives better jitter performance (your MCLK drives everything) but is significantly harder to implement and is more of a UAC2 pattern. Stick with adaptive for V1.

---

## 4. HID — Media Keys and Volume Knob

### 4.1 How HID Works

HID (Human Interface Device) is the simplest USB class. Your device sends small **reports** (just a few bytes) to the PC whenever something happens — a button is pressed, the encoder is turned. The OS interprets these as keyboard/media key events.

For Geist, you need a **Consumer Control** HID report. This is the USB standard for media keys (as opposed to regular keyboard keys). It lets you send:

- Play/Pause
- Next Track
- Previous Track  
- Volume Up / Volume Down

### 4.2 The HID Report Descriptor

The HID Report Descriptor is a weird mini-program written in a stack-based bytecode language. It tells the host the format of the reports you'll send. For Geist's media controls:

```
// Pseudocode — the actual descriptor is packed binary
Usage Page: Consumer (0x0C)         // "I'm a media device"
Usage: Consumer Control (0x01)
Collection: Application
    // --- Buttons (bitmap) ---
    Usage: Play/Pause (0xCD)
    Usage: Scan Next Track (0xB5)
    Usage: Scan Previous Track (0xB6)
    Logical Min: 0
    Logical Max: 1
    Report Size: 1 bit
    Report Count: 3
    Input: Variable                 // 3 bits, one per button
    
    // --- Padding ---
    Report Size: 5 bits
    Report Count: 1
    Input: Constant                 // pad to byte boundary
    
    // --- Volume (relative) ---
    Usage: Volume (0xE0)
    Logical Min: -1
    Logical Max: 1
    Report Size: 8 bits (2 used)
    Report Count: 1
    Input: Variable, Relative      // rotary encoder delta
End Collection
```

The actual HID report your firmware sends is just **2 bytes**:
```
Byte 0: [0 0 0 0 0 | Prev | Next | Play]   ← button bitmap
Byte 1: [-1 / 0 / +1]                        ← volume delta from encoder
```

When you press the Play button → send `[0x01, 0x00]`, then immediately send `[0x00, 0x00]` (release).  
When you rotate the encoder one click CW → send `[0x00, 0x01]` (volume +1).

The PC's OS receives this and adjusts master volume / controls media playback. No drivers needed.

### 4.3 Mapping to Geist Hardware

| Physical Input | GPIO | HID Action |
|---|---|---|
| Alps EC11 rotation (KNOB_A, KNOB_B) | IO4, IO5 | Volume Up/Down (relative) |
| Alps EC11 button (KNOB_SW) | IO6 | Mute toggle (or Play/Pause) |
| Push button (BUTTON_PLAY) | IO16 | Play/Pause |
| Push button (BUTTON_NEXT) | IO10 | Next Track |
| Push button (BUTTON_PREV) | IO8 | Previous Track |
| SPDT Toggle (TOGGLE_MODE) | IO7 | Mode switch (internal only, not HID) |

> [!TIP]
> The rotary encoder needs **debouncing** in firmware. The EC11 is mechanical and will produce bounce noise on each detent. Either debounce in software (ignore transitions faster than ~2ms) or add RC filters (10kΩ + 100nF) on KNOB_A and KNOB_B. Hardware debouncing is cleaner for real-time audio firmware where you don't want CPU time spent on GPIO polling.

---

## 5. CDC ACM — The Companion App Link

### 5.1 What CDC ACM Is

CDC ACM (Communications Device Class — Abstract Control Model) is just a USB serial port. When the host sees this interface, it creates a virtual COM port (Windows: `COM3`, Linux: `/dev/ttyACM0`, macOS: `/dev/cu.usbmodem*`). Your companion app opens this port and sends/receives data — just like UART, but over USB.

### 5.2 The Protocol You Design

This is entirely up to you. You own both ends (firmware + companion app). A simple approach:

```
// Companion app → Geist (PC sends track info)
{"cmd": "track", "title": "Resonance", "artist": "HOME", "album": "Odyssey"}

// Companion app → Geist (PC sends album art)
{"cmd": "art", "width": 240, "height": 240, "format": "rgb565"}
<raw binary pixel data follows>

// Geist → Companion app (device sends status)
{"status": "playing", "volume": 72, "sample_rate": 96000, "mode": "visualizer"}
```

JSON over serial is easy to debug. For album art, you'd send a header then raw RGB565 pixel data (the ST7789 speaks RGB565 natively). A 240×240 image at 2 bytes/pixel = 115,200 bytes — takes about 1 second at 1 Mbps baud.

### 5.3 How the Companion App Gets Track Info

On the PC side, your companion app needs to read the current media session:

- **Windows**: `Windows.Media.Control.GlobalSystemMediaTransportControlsSessionManager` (SMTC API) — C#/.NET, Python via `winsdk`, or Rust via `windows-rs`
- **macOS**: `MRMediaRemoteGetNowPlayingInfo` (private framework, or use `osascript`)
- **Linux**: D-Bus `org.mpris.MediaPlayer2` interface (MPRIS2)

The companion app polls/subscribes to media changes, then pushes updates to Geist over the CDC serial port.

---

## 6. The Complete Data Flow — Putting It All Together

Here is the full picture of everything happening simultaneously inside Geist:

```
┌─────────────────────────────────────────────────────────────────────┐
│                              HOST PC                                │
│                                                                     │
│  ┌─────────────┐   ┌────────────────┐   ┌──────────────────────┐   │
│  │ Music Player │   │ OS Media Keys  │   │ Companion App        │   │
│  │ (Tidal/foobar│   │ Handler        │   │ (reads SMTC/MPRIS)   │   │
│  │  /Spotify)   │   │                │   │                      │   │
│  └──────┬───────┘   └───────▲────────┘   └──────────┬───────────┘   │
│         │ PCM audio         │ key events            │ serial data   │
│         ▼                   │                       ▼               │
│  ┌──────────────────────────┴───────────────────────────────────┐   │
│  │                    USB Host Controller                        │   │
│  │    Isochronous OUT    Interrupt IN       Bulk IN/OUT          │   │
│  └──────────┬────────────────┬─────────────────┬────────────────┘   │
└─────────────┼────────────────┼─────────────────┼────────────────────┘
              │ USB Cable      │                 │
              ▼                ▼                 ▼
┌─────────────────────────────────────────────────────────────────────┐
│                         ESP32-S3 (Geist)                            │
│                                                                     │
│  ┌──────────────────────────────────────────────────────────────┐   │
│  │                    USB Device Peripheral                     │   │
│  │   EP1 OUT (Isoch)     EP2 IN (Interrupt)   EP3 IN/OUT (Bulk)│   │
│  └────┬──────────────────────▲─────────────────────▲──┬────────┘   │
│       │                      │                     │  │            │
│       ▼                      │                     │  ▼            │
│  ┌──────────┐          ┌─────┴──────┐        ┌────┴──────────┐    │
│  │ Ring     │          │ HID Report │        │ CDC Serial    │    │
│  │ Buffer   │          │ Builder    │        │ Parser        │    │
│  │ (DMA)    │          │            │        │               │    │
│  └──┬───┬───┘          └─────▲──────┘        └───────┬───────┘    │
│     │   │                    │                       │            │
│     │   │  ┌─────────┐      │                       ▼            │
│     │   └─►│ FFT     │   ┌──┴──────────┐    ┌──────────────┐    │
│     │      │ Engine  │   │ GPIO        │    │ ST7789 SPI   │    │
│     │      │ (DSP)   │   │ Debounce    │    │ Display      │    │
│     │      └────┬────┘   │             │    │              │    │
│     │           │        │ Encoder     │    │ Mode 1: Track│    │
│     │           └───────►│ Buttons     │    │ Mode 2: FFT  │    │
│     │            spectrum│ Toggle      │    └──────────────┘    │
│     │                    └─────────────┘                        │
│     ▼                                                           │
│  ┌──────────┐                                                   │
│  │ I2S      │                                                   │
│  │ Peripheral│──► BCK, LRCK, DATA ──► PCM5102A ──► OPA1656     │
│  │ (DMA)    │                          (DAC)        (Amp)       │
│  └──────────┘                                        │          │
│                                                      ▼          │
│                                              4.4mm / 3.5mm      │
└─────────────────────────────────────────────────────────────────────┘
```

### The Timing Contract (per millisecond):

```
Every 1ms USB frame:
├── Receive ~288 bytes (48 stereo samples @ 24-bit) from isochronous EP
├── Write samples into the I2S DMA ring buffer
├── (if Mode 2) Copy samples to FFT input buffer  
├── (if FFT buffer full) Run 1024-point FFT (~0.1ms on ESP32-S3 @ 240MHz)
├── (if FFT done) Render spectrum bars to ST7789 framebuffer
├── Poll GPIO state, debounce, queue HID report if changed
└── Check CDC RX buffer, parse any incoming track info
```

This all fits comfortably. The ESP32-S3 has 240MHz dual-core — Core 0 can handle USB+I2S+HID, Core 1 can handle FFT+Display. Embassy's async executor makes this natural.

---

## 7. Sample Rate & Bit Depth — What to Actually Advertise

In your AS Format Descriptor, list these supported formats:

| Sample Rate | Bit Depth | Bytes/Frame | Use Case |
|---|---|---|---|
| 48,000 Hz | 24-bit | 288 | Default — all music, games, voice |
| 96,000 Hz | 24-bit | 576 | Hi-res FLAC files |

**Skip 44,100 Hz.** The ESP32-S3's PLL cannot generate a clean 44.1kHz-family I2S clock (it derives from 40MHz, which doesn't divide cleanly into 44.1k). You'd get fractional dividers and increased jitter. 48kHz is the USB/multimedia standard anyway. If the OS has a 44.1k source, it will resample to 48k — this is normal and every USB DAC does this.

> [!CAUTION]
> If you DO list 44,100 Hz as a supported rate, the OS will send 44.1k samples and expect your I2S clock to be exact. The ESP32's PLL jitter at 44.1k will manifest as audible distortion on sustained tones. Better to not advertise it at all.

---

## 8. Firmware Architecture Overview (Rust + Embassy)

Here is how all of this maps to your Rust firmware project structure:

```
geist-firmware/
├── Cargo.toml
├── src/
│   ├── main.rs              ← Embassy entry point, spawns all tasks
│   │
│   ├── usb/
│   │   ├── mod.rs
│   │   ├── descriptors.rs   ← All USB descriptors (Device, Config, AC, AS, HID, CDC)
│   │   ├── audio.rs         ← UAC1 handler: isochronous RX, buffer management
│   │   ├── hid.rs           ← HID report builder, sends media key events
│   │   └── cdc.rs           ← CDC serial handler, parses companion app messages
│   │
│   ├── audio/
│   │   ├── mod.rs
│   │   ├── i2s.rs           ← I2S DMA driver, feeds PCM5102A
│   │   ├── buffer.rs        ← Lock-free ring buffer between USB and I2S
│   │   └── dsp.rs           ← FFT engine, spectrum analysis
│   │
│   ├── ui/
│   │   ├── mod.rs
│   │   ├── display.rs       ← ST7789 SPI driver, framebuffer management
│   │   ├── encoder.rs       ← EC11 rotary encoder with debounce state machine
│   │   ├── buttons.rs       ← Debounced button handler (prev/play/next)
│   │   └── renderer.rs      ← Screen layouts: track info view, spectrum view
│   │
│   └── app/
│       ├── mod.rs
│       └── state.rs         ← Global state machine (mode, volume, track info)
```

### Task Model (Embassy async):

```
Core 0 (Real-time audio):
  ├── usb_audio_task()      ← Highest priority. Handles isochronous USB RX.
  ├── i2s_feed_task()       ← Drains ring buffer into I2S DMA.
  └── usb_hid_cdc_task()    ← Handles HID reports + CDC serial.

Core 1 (UI + DSP):
  ├── fft_task()            ← Runs FFT when buffer is ready (~every 21ms for 1024 samples at 48k).
  ├── display_task()        ← Renders to ST7789 via SPI DMA (~30fps target).
  └── input_task()          ← Polls encoder + buttons, debounces, updates state.
```

---

## 9. Key Firmware Crates You'll Need

| Crate | Purpose |
|---|---|
| `esp-hal` | Low-level ESP32-S3 peripheral access (I2S, SPI, GPIO, USB) |
| `embassy-executor` | Async task runtime with multi-core support |
| `embassy-usb` | USB device stack — composite device, control endpoints |
| `embassy-time` | Timers, delays, debounce timing |
| `heapless` | Stack-allocated ring buffers, strings (no `alloc` needed) |
| `microfft` | `no_std` FFT implementation, fixed-size transforms |
| `embedded-graphics` | 2D rendering primitives for the ST7789 |
| `mipidsi` | ST7789 display driver (SPI) |
| `serde-json-core` | `no_std` JSON parser for CDC companion protocol |

> [!NOTE]
> You will likely need to implement the UAC1 descriptors manually using `embassy-usb`'s raw descriptor builder. There's no ready-made UAC1 crate. The TinyUSB C library has a working audio device example — use it as your descriptor reference, then translate the structs to Rust.

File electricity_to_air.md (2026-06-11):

# Electricity to Air: The Complete Signal Journey Inside Geist

> *From a USB bit to a pressure wave on your eardrum — every stage, every transistor-level mechanism, every physical transformation.*

This document goes **inside** the ICs. The [Hardware Signal Trace](./hardware_signal_trace.md) covered what happens *between* chips. This covers what happens *within* them.

---

## The Complete Chain at a Glance

```
 Spotify on laptop
       │
       │ USB cable (differential voltage)
       ▼
 ┌─────────────────┐
 │   ESP32-S3       │
 │  ┌─────────┐    │
 │  │ USB PHY │    │  Stage 1: Differential → Digital bits
 │  └────┬────┘    │
 │  ┌────┴────┐    │
 │  │ USB SIE │    │  Stage 2: Protocol decode, extract PCM samples
 │  └────┬────┘    │
 │  ┌────┴────┐    │
 │  │   DMA   │    │  Stage 3: Move samples to memory without CPU
 │  └────┬────┘    │
 │  ┌────┴────┐    │
 │  │ DSP/EQ  │    │  Stage 4: Biquad filters (your parametric EQ)
 │  └────┬────┘    │
 │  ┌────┴────┐    │
 │  │ I2S TX  │    │  Stage 5: Serialize samples into I2S bitstream
 │  └─────────┘    │
 └────────┬────────┘
          │ I2S bus (3 wires: BCLK, LRCK, DATA)
          ▼
 ┌─────────────────┐
 │   PCM5102A       │
 │  ┌─────────┐    │
 │  │ I2S RX  │    │  Stage 6: Deserialize bitstream → parallel words
 │  └────┬────┘    │
 │  ┌────┴────┐    │
 │  │ Interp. │    │  Stage 7: Upsample 48kHz → 6.144 MHz
 │  │ Filter  │    │
 │  └────┬────┘    │
 │  ┌────┴────┐    │
 │  │  Delta  │    │  Stage 8: Multi-bit → 1-bit PDM stream
 │  │  Sigma  │    │
 │  │  Mod    │    │
 │  └────┬────┘    │
 │  ┌────┴────┐    │
 │  │ 1-bit   │    │  Stage 9: Current switches toggle at MHz rates
 │  │ DAC     │    │
 │  └────┬────┘    │
 │  ┌────┴────┐    │
 │  │ Analog  │    │  Stage 10: Low-pass filter → smooth analog voltage
 │  │ Recon.  │    │
 │  └─────────┘    │
 └────────┬────────┘
          │ Analog voltage (~2.1 Vrms)
          ▼
 ┌─────────────────┐
 │   OPA1656 ×2     │
 │  ┌─────────┐    │
 │  │ Diff    │    │  Stage 11: Input differential transistor pair
 │  │ Pair    │    │
 │  └────┬────┘    │
 │  ┌────┴────┐    │
 │  │ Gain    │    │  Stage 12: Voltage amplification stage
 │  │ Stage   │    │
 │  └────┬────┘    │
 │  ┌────┴────┐    │
 │  │ Output  │    │  Stage 13: Class AB push-pull output
 │  │ Stage   │    │
 │  └─────────┘    │
 └────────┬────────┘
          │ Balanced analog (OUT+, OUT-)
          ▼
 ┌─────────────────┐
 │   Headphone      │
 │  ┌─────────┐    │
 │  │ Voice   │    │  Stage 14: Current → magnetic force
 │  │ Coil    │    │
 │  └────┬────┘    │
 │  ┌────┴────┐    │
 │  │ Diaphr. │    │  Stage 15: Force → mechanical motion
 │  └────┬────┘    │
 │  ┌────┴────┐    │
 │  │ Air     │    │  Stage 16: Motion → pressure wave → your eardrum
 │  └─────────┘    │
 └─────────────────┘
```

---

## Chapter 1: The ESP32-S3 — Digital Signal Processing Engine

### 1.1 The USB PHY — Turning Voltage Into Bits

When you plug the USB cable in, the D+ and D- lines carry **differential signals**. This means the data isn't encoded as "high = 1, low = 0" on a single wire. Instead, two wires carry *opposite* voltages, and the receiver looks at the *difference* between them:

```
USB Full-Speed Signaling (12 Mbps):

D+ ───╲  ╱───╲  ╱───────╲  ╱───
       ╲╱    ╲╱         ╲╱
D- ───╱  ╲───╱  ╲───────╱  ╲───
       ╱╲    ╱╲         ╱╲

     J    K    J       J    K     ← line states

     D+ > D- = J state
     D- > D+ = K state
```

**Why differential?** Any electromagnetic noise picked up by the cable hits *both* wires equally. When the PHY subtracts D+ from D-, the noise cancels out:

```
D+ with noise:   signal + noise
D- with noise:  -signal + noise
─────────────────────────────────
D+ minus D-:    2 × signal         ← noise gone, signal doubled
```

Inside the ESP32-S3, the **USB PHY** (Physical Layer) is a small analog circuit at the very edge of the silicon die:

```
┌─── ESP32-S3 USB PHY (on-die analog) ───────────────────────┐
│                                                              │
│  D+ pin ──→ ┌──────────────┐                                │
│              │ Differential │──→ Raw bit    ┌───────────┐   │
│  D- pin ──→ │  Comparator  │    stream  ──→│ NRZI      │   │
│              └──────────────┘               │ Decoder   │──→│ byte stream
│                                             └───────────┘   │
│  Internal:                                                   │
│  • 1.5kΩ pull-up on D+ (identifies as Full-Speed device)    │
│  • ESD protection diodes                                     │
│  • 45Ω termination resistors (match cable impedance)        │
│  • Clock recovery PLL (extracts 12 MHz clock from data)     │
│                                                              │
└──────────────────────────────────────────────────────────────┘
```

The **differential comparator** is literally two transistors arranged as a long-tailed pair:

```
                    Vdd
                   ╱   ╲
                  R     R      ← matched load resistors
                  │     │
          out- ───┤     ├─── out+
                  │     │
    D+ ──┤gate  Q1     Q2  gate├── D-
                  │     │
                  └──┬──┘
                     │
                     R         ← tail current source
                     │
                    GND

If D+ > D-:  Q1 conducts more → out+ goes LOW, out- goes HIGH → logic "J"
If D- > D+:  Q2 conducts more → out+ goes HIGH, out- goes LOW → logic "K"
```

This tiny circuit — two transistors and two resistors — is the very first thing that touches your audio data.

The **NRZI decoder** then converts the J/K transitions into actual bits. In USB, a "0" bit is encoded as a *transition* (J→K or K→J), and a "1" bit is encoded as *no transition* (stay in current state). This is called NRZI (Non-Return-to-Zero Inverted):

```
Line state: J  K  K  J  K  J  J  J  K  K
Transition:    ↕  ·  ↕  ↕  ↕  ·  ·  ↕  ·
NRZI bit:      0  1  0  0  0  1  1  0  1
```

### 1.2 The USB SIE — Protocol Engine

After the PHY produces a raw byte stream, the **Serial Interface Engine** (SIE) handles the USB protocol:

```
┌─── USB SIE (hardware state machine) ───────────────────────┐
│                                                              │
│  Byte stream ──→ ┌──────────┐    ┌───────────┐             │
│                  │ Packet   │──→ │ CRC Check │             │
│                  │ Detector │    │ (CRC-16)  │             │
│                  └──────────┘    └─────┬─────┘             │
│                                        │                    │
│                                  ┌─────┴─────┐             │
│                                  │ Endpoint   │             │
│                                  │ Router     │──→ EP1 (Audio Isochronous)
│                                  │            │──→ EP2 (HID Interrupt)
│                                  │            │──→ EP3 (CDC Bulk)
│                                  └────────────┘             │
│                                                              │
│  The SIE automatically:                                      │
│  • Responds to SETUP packets (enumeration)                  │
│  • Routes data to correct endpoint buffers                  │
│  • Generates ACK/NAK handshakes                             │
│  • Handles SOF (Start of Frame) every 1ms                   │
│                                                              │
└──────────────────────────────────────────────────────────────┘
```

**USB Audio Class** uses **isochronous transfers** — the host sends a packet of audio samples every 1ms (one USB frame). For 48kHz stereo 24-bit audio:

```
Every 1ms USB frame:
┌────────────────────────────────────────────────┐
│ 48 samples × 2 channels × 3 bytes = 288 bytes │
│                                                │
│ Sample 1L: [byte2][byte1][byte0]  ← 24 bits   │
│ Sample 1R: [byte2][byte1][byte0]               │
│ Sample 2L: [byte2][byte1][byte0]               │
│ Sample 2R: [byte2][byte1][byte0]               │
│ ...                                            │
│ Sample 48L: [byte2][byte1][byte0]              │
│ Sample 48R: [byte2][byte1][byte0]              │
└────────────────────────────────────────────────┘

48 samples/frame × 1000 frames/second = 48,000 samples/second = 48 kHz ✓
```

### 1.3 DMA — Data Movement Without the CPU

The audio data now sits in the USB endpoint buffer (a small hardware FIFO inside the SIE). Getting it to memory for processing requires the **DMA (Direct Memory Access) controller**:

```
┌─── DMA Controller ────────────────────────────────────┐
│                                                        │
│  USB EP1 Buffer ──→ ┌──────────┐ ──→ SRAM Buffer      │
│  (hardware FIFO)    │ DMA Ch.  │     (ring buffer)    │
│                     │ Engine   │                       │
│                     └──────────┘                       │
│                                                        │
│  The DMA engine is an independent hardware unit.       │
│  It has its own bus master interface to SRAM.          │
│  It copies data while the CPU does other things        │
│  (running your EQ, updating the display, etc.)         │
│                                                        │
│  When a transfer completes, it fires an interrupt      │
│  to notify the CPU: "48 new samples are ready"         │
│                                                        │
└────────────────────────────────────────────────────────┘
```

Without DMA, the CPU would spend ~30% of its time just copying bytes from the USB buffer to memory. With DMA, the CPU spends 0% — it just gets an interrupt when new data arrives.

### 1.4 The Parametric EQ — Biquad Filters in Real-Time

Now the CPU gets involved. Your 10-band parametric EQ is a chain of **biquad IIR filters**. Each band is implemented as a second-order filter with 5 coefficients (b0, b1, b2, a1, a2):

```
One biquad filter (Direct Form I):

x[n] ──→(×b0)──→(+)──→ y[n]
              ↗   ↑
x[n-1]→(×b1)─┘   │
              ↗   │
x[n-2]→(×b2)─┘   │
                   │
y[n-1]→(×a1)──────┘
              ↗
y[n-2]→(×a2)─┘

y[n] = b0·x[n] + b1·x[n-1] + b2·x[n-2] - a1·y[n-1] - a2·y[n-2]

Operations per sample per band:
  5 multiplications + 4 additions = 9 operations

For 10 bands, stereo, 48kHz:
  9 × 10 × 2 × 48,000 = 8,640,000 operations/second

ESP32-S3 at 240 MHz with single-cycle multiply:
  240,000,000 / 8,640,000 = 27.8× headroom  ← plenty
```

The companion app computes the filter coefficients on the PC and sends them over CDC serial. The ESP32 just applies them — multiply and add, multiply and add, 10 times per sample.

```
10-band EQ chain:

Sample in → [Band 1] → [Band 2] → [Band 3] → ... → [Band 10] → Sample out
             60 Hz     150 Hz     400 Hz              16 kHz

Each band:
  • Center frequency (set by user): 60 Hz to 16 kHz
  • Gain (set by user): -12 dB to +12 dB
  • Q factor (set by user): 0.5 to 10.0
  
  These three parameters → companion app computes b0,b1,b2,a1,a2
                         → sends 5 floats over USB serial
                         → ESP32 stores them and applies in real-time
```

### 1.5 The I2S Transmitter — Serializing to the DAC

After EQ processing, the samples need to get to the PCM5102A. The ESP32's **I2S peripheral** serializes 32-bit words into a precisely-timed bitstream:

```
┌─── I2S TX Peripheral ─────────────────────────────────────┐
│                                                            │
│  SRAM ──→ ┌──────┐ ──→ ┌──────────────┐ ──→ DATA pin     │
│   (DMA)   │ FIFO │     │ Shift        │                   │
│           │ 32×  │     │ Register     │                   │
│           └──────┘     │ (parallel →  │                   │
│                        │  serial)     │                   │
│                        └──────────────┘                   │
│                                                            │
│  Clock generator:                                          │
│  MCLK (master) ──÷──→ BCLK (bit clock) ──→ BCLK pin      │
│                  ──÷──→ LRCK (L/R select) ──→ LRCK pin   │
│                                                            │
│  For 48kHz, 32-bit, stereo:                               │
│    LRCK = 48,000 Hz (one toggle per sample)               │
│    BCLK = 48,000 × 32 × 2 = 3,072,000 Hz (3.072 MHz)    │
│                                                            │
└────────────────────────────────────────────────────────────┘
```

What the three wires actually look like on an oscilloscope:

```
LRCK:  ┌──────────────────┐                    ┌──────────────────┐
       │   LEFT channel   │   RIGHT channel    │   LEFT channel
  ─────┘                  └────────────────────┘

BCLK:  ┌┐┌┐┌┐┌┐┌┐┌┐┌┐┌┐┌┐┌┐┌┐┌┐┌┐┌┐┌┐┌┐┌┐┌┐┌┐┌┐┌┐┌┐┌┐┌┐┌┐┌┐┌┐┌┐
  ─────┘└┘└┘└┘└┘└┘└┘└┘└┘└┘└┘└┘└┘└┘└┘└┘└┘└┘└┘└┘└┘└┘└┘└┘└┘└┘└┘└┘└┘└

DATA:  ─╳─╳─╳─╳─╳─╳─╳─╳─╳─╳─╳─╳─╳─╳─╳─╳─╳─╳─╳─╳─╳─╳─╳─╳─╳─╳─╳─
        MSB...............LSB  padding   MSB...............LSB  padding
        ◄── 24 data bits ──►  ◄─ 8 ──►  ◄── 24 data bits ──►  ◄─ 8 ──►
        ◄──── LEFT sample ─────────────► ◄──── RIGHT sample ──────────►

Each data bit is clocked on the FALLING edge of BCLK.
The DAC reads each bit on the RISING edge of BCLK.
LRCK LOW = left channel. LRCK HIGH = right channel.
```

---

## Chapter 2: The PCM5102A — Turning Numbers Into Voltage

This is where the magic happens. A 24-bit integer becomes a precise analog voltage. The PCM5102A does this through a multi-stage pipeline that is genuinely elegant.

### 2.1 The I2S Receiver — Reassembling the Bitstream

The first stage reverses what the ESP32's I2S TX did. A shift register clocked by BCLK captures each incoming bit and assembles them back into a parallel 24-bit word:

```
┌─── I2S Receiver ──────────────────────────────┐
│                                                │
│  DATA pin ──→ ┌────────────────────────────┐  │
│               │ 24-bit Shift Register      │  │
│  BCLK pin ──→ │ clocked on rising edge     │──→ 24-bit parallel word
│               └────────────────────────────┘  │
│                                                │
│  LRCK pin ──→ ┌────────────────┐              │
│               │ L/R Demux      │──→ Left sample register
│               │                │──→ Right sample register
│               └────────────────┘              │
│                                                │
│  When LRCK transitions:                        │
│    1. Current shift register → output latch    │
│    2. Shift register resets for next sample    │
│                                                │
└────────────────────────────────────────────────┘
```

### 2.2 The Interpolation Filter — Upsampling

Here's the first non-obvious thing the DAC does. Your audio is sampled at 48 kHz, meaning the highest frequency it can represent is 24 kHz (Nyquist theorem). But if you try to convert 48 kHz samples directly to analog, you'd need a very steep analog low-pass filter to remove the "images" above 24 kHz. Steep analog filters are expensive and introduce phase distortion.

Instead, the PCM5102A **upsamples digitally** — it increases the sample rate by 128×, inserting interpolated samples between each original sample:

```
Original signal at 48 kHz (only 48,000 points per second):

  ●         ●                   ●         ●
      ●         ●           ●       ●
          ●         ●   ●               ●
              ●       ●                     ●
  └──────────────────────────────────────────┘
  One period of a 1 kHz sine wave = 48 samples

After 128× interpolation (6,144,000 points per second):

  ●●●●●●●●●●●●●●●●●●●●●●●●●●●●●●●●●●●●●●●●●●
  ●●●●●●●●●●●●●●●●●●●●●●●●●●●●●●●●●●●●●●●●●●
  ●●●●●●●●●●●●●●●●●●●●●●●●●●●●●●●●●●●●●●●●●●
  └──────────────────────────────────────────┘
  Same period, but now 6,144 samples — much smoother

This is done with a multi-stage FIR (Finite Impulse Response) filter.
Each stage doubles the sample rate while filtering out spectral images.
```

The PCM5102A uses a **3-stage cascaded half-band FIR filter**:

```
48 kHz ──→ [Stage 1: ×2] ──→ 96 kHz ──→ [Stage 2: ×2] ──→ 192 kHz
  ──→ [Stage 3: ×2] ──→ 384 kHz ──→ ... ──→ [Final: ×32] ──→ 6.144 MHz

Each stage:
  1. Insert a zero between every sample (zero-stuffing)
  2. Apply a low-pass FIR filter to remove the spectral image
  3. Result: double the sample rate with no aliasing artifacts

Why multi-stage? A single 128× interpolation would need a 
~10,000-tap FIR filter. Cascading 7 stages of ×2 needs only
~100 taps total. Same result, 100× less computation.
```

### 2.3 The Delta-Sigma Modulator — The Heart of the DAC

This is the most conceptually difficult stage and the most brilliant. The interpolated 24-bit samples at 6.144 MHz need to become an analog voltage. Building a 24-bit accurate voltage reference with 16 million distinct levels is essentially impossible with practical electronics.

Instead, the PCM5102A uses a **delta-sigma modulator** to convert the multi-bit signal into a **1-bit stream** at very high speed. The key insight: you can trade **amplitude resolution** for **time resolution**.

```
The core idea:

  24-bit sample = 0.75 (¾ of full scale)

  Instead of outputting exactly 0.75V once:
  
  Output a stream of 1s and 0s where 75% are 1s:
  
  1 1 1 0 1 1 1 0 1 1 1 0 1 1 1 0 ...
  
  Average value = 12/16 = 0.75 ✓
  
  But we need the PATTERN of 1s and 0s to be shaped
  so that the quantization error (noise) is pushed
  to ultrasonic frequencies where it's inaudible.
```

The delta-sigma modulator is a **feedback loop** that continuously compares its 1-bit output to the desired multi-bit input, and shapes the error:

```
┌─── 4th-Order Delta-Sigma Modulator ──────────────────────────────┐
│                                                                    │
│  24-bit      ┌───┐   ┌───┐   ┌───┐   ┌───┐   ┌─────────┐       │
│  input ──(+)─┤ ∫ ├─(+)─┤ ∫ ├─(+)─┤ ∫ ├─(+)─┤ ∫ ├──→│ 1-bit   │──→ 1-bit
│           ↑  └───┘  ↑  └───┘  ↑  └───┘  ↑  └───┘  │ Quantizer│   output
│           │         │         │         │          └─────────┘       │
│           │         │         │         │               │           │
│           └─────────┴─────────┴─────────┴───── DAC ─────┘           │
│                                                 (1-bit feedback)    │
│                                                                      │
│  The ∫ blocks are integrators (accumulators).                       │
│  4th-order means 4 integrators in cascade.                          │
│  Each integrator adds another 20 dB/decade of noise shaping.       │
│                                                                      │
│  The quantizer is literally a comparator:                           │
│    input > 0 → output = 1                                           │
│    input ≤ 0 → output = 0                                           │
│                                                                      │
└──────────────────────────────────────────────────────────────────────┘
```

**What "noise shaping" means visually:**

```
Frequency spectrum of quantization noise:

Without noise shaping (traditional DAC):

  Noise ▲
  level │████████████████████████████████████████
        │████████████████████████████████████████
        │████████████████████████████████████████  ← flat noise everywhere
        └────────────────────────────────────────→ Frequency
        20Hz                                  3MHz

With 4th-order delta-sigma noise shaping:

  Noise ▲
  level │                                ████████
        │                           █████████████
        │                      ██████████████████
        │                 ███████████████████████  ← noise pushed HIGH
        │░░░░░░░░░░░█████████████████████████████
        └────────────────────────────────────────→ Frequency
        20Hz    24kHz                         3MHz
         ↑                                    ↑
    Audio band: nearly                   Ultrasonic:
    zero noise (112 dB SNR)              lots of noise (filtered out later)
```

The noise hasn't been eliminated — it's been **moved** to frequencies you can't hear. This is the fundamental trick that makes affordable hi-res DACs possible.

### 2.4 The 1-Bit DAC — Current Switches

The 1-bit output stream from the delta-sigma modulator drives a deceptively simple circuit — a pair of matched current sources that toggle at ~6 MHz:

```
                    +3.3V (AVDD)
                      │
                ┌─────┴─────┐
                │   PMOS    │
                │  current  │
                │  source   │
                │  (Iref)   │
                └─────┬─────┘
                      │
            ┌─────────┼─────────┐
            │         │         │
     ┌──────┴──┐            ┌──┴──────┐
     │  SW_P   │            │  SW_N   │
     │ (PMOS)  │            │ (NMOS)  │
     └────┬────┘            └────┬────┘
          │                      │
          ├──────── VOUT ────────┤
          │                      │
     ┌────┴────┐            ┌────┴────┐
     │  SW_N   │            │  SW_P   │
     │ (NMOS)  │            │ (PMOS)  │
     └────┬────┘            └────┬────┘
          │         │         │
          └─────────┼─────────┘
                    │
                ┌───┴─────┐
                │  NMOS   │
                │ current │
                │  sink   │
                │ (-Iref) │
                └────┬────┘
                     │
                    GND

When 1-bit output = 1:  SW_P closes top-left, SW_N closes bottom-right
                        → Current flows into VOUT → positive voltage

When 1-bit output = 0:  SW_N closes top-right, SW_P closes bottom-left
                        → Current flows out of VOUT → negative voltage

The switches toggle at ~6 MHz. The current sources are matched 
to <0.01% accuracy using laser-trimmed thin-film resistors on-die.
```

The key to DAC linearity: with only 1 bit, there are only 2 levels (Iref and -Iref). You don't need 16 million matched levels — you just need 2 perfectly matched current sources. A 1-bit DAC is inherently perfectly linear. All the complexity is in the delta-sigma modulator that decides *when* to toggle.

### 2.5 The Analog Reconstruction Filter — Smoothing

The 1-bit stream at 6 MHz is now an analog signal, but it's a square wave switching between +Iref and -Iref at megahertz rates. It needs to be low-pass filtered to extract the audio band:

```
┌─── Internal Reconstruction Filter ──────────────────┐
│                                                       │
│  1-bit switching ──→ ┌───────────────┐ ──→ OUTL pin  │
│  current            │ 3rd-order     │     (smooth    │
│                     │ Butterworth   │      analog)   │
│                     │ LPF          │                 │
│                     │ fc ≈ 100 kHz │                 │
│                     └───────────────┘                 │
│                                                       │
│  The filter removes everything above ~100 kHz.        │
│  Your audio (20 Hz - 24 kHz) passes through.         │
│  The shaped quantization noise (above 24 kHz) is      │
│  heavily attenuated.                                  │
│                                                       │
│  What remains is a smooth analog voltage that is      │
│  faithful to the original digital samples within      │
│  112 dB of the full-scale output.                     │
│                                                       │
│  External caps CAPP and CAPM (C10, C11 on your PCB)  │
│  provide additional filtering of the charge pump's    │
│  internal voltage doubler.                            │
│                                                       │
└───────────────────────────────────────────────────────┘
```

After this filter, the signal at OUTL and OUTR is a clean analog voltage:
- **Full scale:** 2.1 Vrms (297 mVp-p with a 1 kHz sine at -6 dBFS)
- **SNR:** 112 dB (A-weighted) — meaning the noise floor is 5.3 µV
- **THD:** -93 dB — harmonic distortion is 0.002% of the signal
- **Output impedance:** ~200Ω (needs buffering for headphones — that's what the OPA1656 is for)

---

## Chapter 3: The OPA1656 — Precision Analog Amplification

The DAC output is too weak to drive headphones directly (200Ω output impedance into 32Ω headphones would lose most of the signal as voltage division). The OPA1656 op-amp buffers and converts to balanced output.

### 3.1 Inside an Op-Amp — Three Stages

The OPA1656 contains roughly ~80 transistors organized into three stages:

```
┌─── OPA1656 Internal Architecture ───────────────────────────────────┐
│                                                                       │
│  IN+ ──┐    ┌─────────────────┐   ┌───────────────┐   ┌──────────┐ │
│         ├──→│  Input Stage    │──→│  Gain Stage   │──→│  Output  │──→ OUT
│  IN- ──┘    │  (Differential  │   │  (Voltage     │   │  Stage   │ │
│             │   Pair)         │   │   Amplifier)  │   │  (Class  │ │
│             │                 │   │               │   │   AB)    │ │
│             │  Gain: ~60 dB   │   │  Gain: ~40 dB │   │  Gain:  │ │
│             │  Input bias:    │   │               │   │  ~1 (0  │ │
│             │  0.2 pA (JFET)  │   │               │   │   dB)   │ │
│             └─────────────────┘   └───────────────┘   └──────────┘ │
│                                                                       │
│  Total open-loop gain: ~100 dB (100,000×)                            │
│  With negative feedback, closed-loop gain = set by external R ratio  │
│                                                                       │
│  Miller compensation capacitor between gain stage and output:        │
│  This small (~15 pF) internal cap prevents the op-amp from           │
│  oscillating by rolling off the gain smoothly at high frequencies.   │
│                                                                       │
└───────────────────────────────────────────────────────────────────────┘
```

### 3.2 The Input Stage — JFET Differential Pair

The OPA1656 uses **JFET (Junction Field-Effect Transistor)** inputs instead of BJT or CMOS. This is why it's special for audio:

```
                        +4.5V
                       ╱   ╲
                     Rd     Rd     ← drain resistors (matched)
                      │     │
            Vout- ────┤     ├──── Vout+
                      │     │
    IN+ ──┤gate  J1     J2  gate├── IN-        ← JFET differential pair
                      │     │
                      └──┬──┘
                         │
                        Itail       ← constant current source (~1 mA)
                         │
                       -4.5V

Why JFETs for audio:
  • Input bias current: 0.2 pA (picoamps!)
    BJT input: ~100 nA = 500,000× more current drawn from source
    JFET: essentially zero loading on the DAC output
    
  • Input voltage noise: 4.5 nV/√Hz
    This means at audio bandwidth (20 kHz):
    Total input noise = 4.5 × √20000 = 636 nV = 0.636 µV
    That's 70 dB below a 1 mV signal — inaudible
    
  • No 1/f noise corner issues in audio band
    BJTs have popcorn noise. JFETs don't.
```

The differential pair works by **steering current**. When IN+ is slightly more positive than IN-, transistor J1 conducts slightly more current than J2. The difference in drain currents creates a voltage difference at the outputs. This voltage difference is the amplified version of the input difference.

The gain of this stage alone is about 60 dB (1000×). But the op-amp needs to be stable with feedback, so the overall gain is rolled off by the Miller compensation.

### 3.3 The Output Stage — Driving Headphones

The output stage is a **Class AB push-pull** arrangement that can both source and sink current:

```
                    +4.5V
                      │
                ┌─────┴─────┐
                │   Q_NPN   │
                │  (source  │  ← conducts during positive half-cycles
                │  current) │
                └─────┬─────┘
                      │
        Gain stage ───┤──── OUT pin ──→ to headphones
                      │
                ┌─────┴─────┐
                │   Q_PNP   │
                │  (sink    │  ← conducts during negative half-cycles
                │  current) │
                └─────┬─────┘
                      │
                    -4.5V

Class AB biasing:
  Both transistors are biased to conduct a small "idle" current
  (~1 mA) even with no signal. This eliminates "crossover 
  distortion" — the glitch that would occur when one transistor
  turns off and the other turns on at the zero-crossing point.

  Without Class AB bias (Class B):
  
  Output: ╱╲  ╱╲  ╱╲     ← clean sine
          ╱ ╲╱ ╲╱ ╲
          
  Becomes: ╱╲  ╱╲  ╱╲   ← distorted at zero crossings  
           ╱·╲╱·╲╱·╲    
           ↑ glitch (crossover distortion)

  With Class AB: smooth handoff, no glitch.
```

### 3.4 How Feedback Sets the Gain — Your Circuit

In Geist, each OPA1656 package contains two op-amps (A and B). They're configured as:

```
Channel A — Unity-Gain Buffer (non-inverting, gain = +1):

                    ┌─────────┐
  DAC_OUT ──────────┤+   OPA  ├──────────── OUT+ (hot)
                    │   1656A │
              ┌─────┤-        │
              │     └─────────┘
              │          │
              └──────────┘     ← 100% feedback = gain of exactly 1
              
  Vout = Vin × (1 + Rf/Rg)
       = Vin × (1 + 0/∞)
       = Vin × 1
       = Vin                   ← buffer, no voltage gain

  Purpose: transform the DAC's 200Ω output to ~0.001Ω output
           so headphones see a stiff voltage source

Channel B — Inverting Unity-Gain (gain = -1):

                         Rf (10kΩ, R8/R10)
                    ┌───/\/\/\/───┐
                    │             │
                    │ ┌─────────┐ │
  DAC_OUT ──/\/\/──┤─┤-   OPA  ├─┴──────── OUT- (cold)
           Rin      │ │   1656B │
          (10kΩ,    │ ┤+        │
          R9/R11)   │ └────┬────┘
                    │      │
                    │     GND
                    │
                    
  Vout = -Vin × (Rf / Rin)
       = -Vin × (10k / 10k)
       = -Vin                  ← inverted copy of the signal

  Purpose: create the "cold" leg of the balanced signal
```

The balanced output (OUT+ and OUT-) carries the same signal, but one is inverted. The headphone driver in your IEMs subtracts them:

```
Signal received by headphone driver:

  OUT+ = +V (hot)
  OUT- = -V (cold)
  
  Driver sees: OUT+ minus OUT- = V - (-V) = 2V
  
  Any noise picked up equally on both wires:
  OUT+ = +V + noise
  OUT- = -V + noise
  
  Driver sees: (+V + noise) - (-V + noise) = 2V + 0
  
  Noise cancelled. Signal doubled.
```

---

## Chapter 4: Voltage to Sound — The Transduction

### 4.1 The Voice Coil — Electricity Becomes Force

Inside every headphone driver (dynamic, BA, or planar) is a **conductor in a magnetic field**. When current flows through it, the Lorentz force pushes it:

```
┌─── Dynamic Driver Cross-Section ───────────────────┐
│                                                      │
│            Diaphragm (thin mylar/bio-cellulose)     │
│         ╱─────────────────────────────────╲         │
│        ╱                                   ╲        │
│       ╱                                     ╲       │
│      │          ┌───────────────┐            │      │
│      │          │  Voice Coil   │ ← current  │      │
│      │          │  (copper wire │   flows     │      │
│      │          │   wound in    │   here      │      │
│      │          │   a cylinder) │            │      │
│      │          └───────┬───────┘            │      │
│      │                  │                    │      │
│      │    N ════════════╪═══════════ S       │      │
│      │    ↑   permanent │ magnetic   ↑       │      │
│      │    magnet        │ field      magnet  │      │
│      │                  │                    │      │
│      └──────────────────┴────────────────────┘      │
│                         │                            │
│                      Surround                        │
│                   (flexible edge)                    │
│                                                      │
│  F = B × I × L                                      │
│                                                      │
│  F = force on the coil (Newtons)                    │
│  B = magnetic field strength (~1 Tesla)             │
│  I = current through coil (milliamps)               │
│  L = length of wire in the field (~1 meter wound)   │
│                                                      │
│  For a 32Ω headphone at 1 Vrms:                    │
│  I = V/R = 1/32 = 31.25 mA                         │
│  F = 1 × 0.03125 × 1 = 31.25 milliNewtons          │
│                                                      │
│  That tiny force, applied to a <1 gram diaphragm,   │
│  produces accelerations of ~30 m/s² — enough to     │
│  vibrate the diaphragm hundreds to thousands of      │
│  times per second.                                   │
│                                                      │
└──────────────────────────────────────────────────────┘
```

### 4.2 The Diaphragm — Force Becomes Air Pressure

The voice coil is glued to a thin diaphragm (typically 6-50mm diameter, 10-50 µm thick). When the coil moves, the diaphragm moves with it, pushing and pulling air molecules:

```
Audio signal voltage over time (1 kHz sine):

  +V ─── ╱╲      ╱╲      ╱╲
          ╱  ╲    ╱  ╲    ╱  ╲
  0  ────╱────╲──╱────╲──╱────╲──
         ╱    ╲╱╱    ╲╱╱    ╲╱
  -V ───╱      ╱      ╱

Maps to diaphragm position:

  Forward ─── ╱╲      ╱╲      ╱╲
              ╱  ╲    ╱  ╲    ╱  ╲
  Rest   ────╱────╲──╱────╲──╱────╲──    ← ~10 µm displacement
              ╱    ╲╱╱    ╲╱╱    ╲╱
  Backward ──╱      ╱      ╱

Maps to air pressure at your eardrum:

  High   ─── ╱╲      ╱╲      ╱╲
              ╱  ╲    ╱  ╲    ╱  ╲
  Ambient ───╱────╲──╱────╲──╱────╲──    ← ~0.1 Pa pressure variation
              ╱    ╲╱╱    ╲╱╱    ╲╱        (vs 101,325 Pa atmospheric)
  Low    ────╱      ╱      ╱

The pressure variation that constitutes "loud music" is about
0.00001% of atmospheric pressure. Your ear is absurdly sensitive.
```

### 4.3 The Numbers — Full Chain

Let's trace an actual sample value through the entire chain:

```
Step 1: Spotify sends sample value 0x5A8000 (24-bit, left channel)
        Decimal: 5,931,008 out of 8,388,608 maximum
        Fraction: 0.707 of full scale = -3 dBFS

Step 2: ESP32 receives via USB, applies EQ (no change at flat EQ)
        Sends 0x5A8000 via I2S to PCM5102A

Step 3: PCM5102A interpolates: 48k → 6.144M samples/sec
        Delta-sigma modulates to 1-bit stream:
        Average density of 1s = 70.7%

Step 4: PCM5102A analog output:
        VOUT = 0.707 × 2.1 Vrms = 1.485 Vrms
        Peak voltage = 1.485 × √2 = 2.1 Vpeak

Step 5: OPA1656A buffer: OUT+ = +1.485 Vrms
        OPA1656B inverter: OUT- = -1.485 Vrms
        
        Balanced differential: 2 × 1.485 = 2.97 Vrms

Step 6: Through 2.2Ω output resistors (R12-R15):
        Negligible voltage drop at headphone currents

Step 7: At 32Ω headphone:
        Current = 2.97V / 32Ω = 92.8 mA peak (!)
        Power = 2.97² / 32 = 275 mW

        Actually, the OPA1656 current limits at ~40 mA,
        so max power into 32Ω ≈ (40mA × 32Ω)² / 32 = 51 mW
        That's still VERY loud — about 120 dB SPL with typical IEMs

Step 8: Voice coil force:
        F = B × I × L = 1T × 0.04A × 1m = 40 mN

Step 9: Diaphragm acceleration:
        a = F/m = 0.04N / 0.001kg = 40 m/s²
        
Step 10: Air pressure variation at eardrum:
         ~2 Pa peak (about 100 dB SPL)
         Your brain interprets this as music.
```

---

## Chapter 5: The Invisible Clocks — Why Timing Matters

Every stage in this chain is governed by clocks, and clock quality directly affects audio quality.

### 5.1 Jitter — The Enemy of Digital Audio

**Jitter** is the random variation in clock timing. If the I2S BCLK edge arrives 100 picoseconds early on one cycle and 100 picoseconds late on the next, the DAC converts the sample at slightly the wrong instant:

```
Ideal BCLK (perfect timing):
  ┌──┐  ┌──┐  ┌──┐  ┌──┐  ┌──┐
  │  │  │  │  │  │  │  │  │  │
──┘  └──┘  └──┘  └──┘  └──┘  └──

Real BCLK (with jitter):
  ┌──┐  ┌──┐ ┌──┐   ┌──┐ ┌──┐
  │  │  │  │ │  │   │  │ │  │
──┘  └──┘  └─┘  └───┘  └─┘  └──
              ↑        ↑
              early    late   ← timing error = jitter

Effect on a 20 kHz sine wave with 1 ns RMS jitter:
  SNR degradation = 20 × log₁₀(1 / (2π × 20000 × 1e-9))
                  = 20 × log₁₀(7958)
                  = 78 dB

  So 1 ns of jitter limits your SNR to 78 dB at 20 kHz.
  For 112 dB SNR, you need jitter below ~15 picoseconds RMS.
```

The PCM5102A solves this with its **internal PLL (Phase-Locked Loop)**. It regenerates a clean clock from the incoming BCLK, filtering out most of the jitter:

```
┌─── PCM5102A Internal PLL ────────────────────────┐
│                                                    │
│  BCLK ──→ ┌──────────┐   ┌──────┐   ┌────────┐  │
│  (jittery) │ Phase    │──→│ Loop │──→│  VCO   │──→ Internal master clock
│            │ Detector │   │Filter│   │(voltage│   (clean, low jitter)
│  ┌────────→│          │   │(LPF) │   │control │  │
│  │         └──────────┘   └──────┘   │osc.)   │  │
│  │                                    └───┬────┘  │
│  │                                        │       │
│  │         ┌──────────┐                   │       │
│  └─────────┤ Divider  │←──────────────────┘       │
│            │ (÷N)     │                           │
│            └──────────┘                           │
│                                                    │
│  The PLL locks to the average frequency of BCLK   │
│  but its VCO output has much lower jitter because  │
│  the loop filter averages out the random timing    │
│  variations.                                       │
│                                                    │
└────────────────────────────────────────────────────┘
```

This is why the PCM5102A's SCK pin can be left unconnected (tied to GND via R7 on your board) — the internal PLL generates its own master clock from BCLK alone. Convenient and effective.

---

## Summary: The Complete Transform

```
USB cable:     Differential voltage swings (±400 mV) at 12 MHz
                            │
                            ▼
ESP32 USB PHY: Comparator → bits → NRZI decode → bytes
                            │
                            ▼
ESP32 SIE:     Protocol decode → extract 24-bit PCM samples
                            │
                            ▼
ESP32 DMA:     Hardware copy to SRAM ring buffer
                            │
                            ▼
ESP32 CPU:     Biquad IIR filter chain (10-band parametric EQ)
                            │
                            ▼
ESP32 I2S TX:  Parallel → serial shift register → 3-wire bus
                            │
                            ▼
PCM5102A RX:   Serial → parallel → 24-bit sample words
                            │
                            ▼
PCM5102A:      128× interpolation → delta-sigma → 1-bit @ 6.144 MHz
                            │
                            ▼
PCM5102A:      Matched current switches → analog reconstruction filter
                            │
                            ▼
OPA1656:       JFET differential pair → gain stage → Class AB output
                            │
                            ▼
Headphone:     Current → magnetic force → diaphragm motion → air pressure
                            │
                            ▼
Your eardrum:  Pressure variation → mechanical motion → nerve impulses
                            │
                            ▼
Your brain:    "Oh, I like this song"
```

> From a ±400 millivolt differential wiggle on a USB cable to a ±2 Pascal pressure variation on a membrane in your inner ear — 16 transformations across 5 different physical domains (electrical, digital, analog, mechanical, acoustic) — all happening 48,000 times per second, within 2 milliseconds end-to-end.
>
> That's what Geist does.

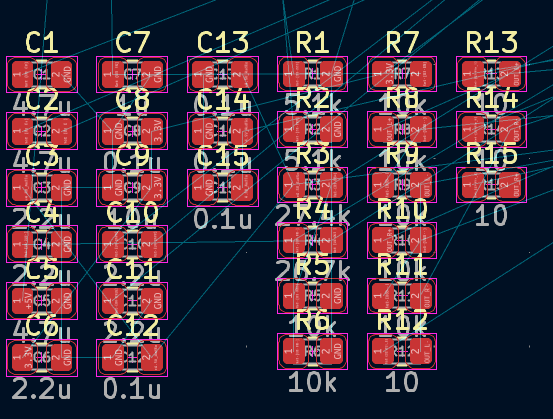
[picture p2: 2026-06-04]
Screenshot 2026-05-27 234251.png

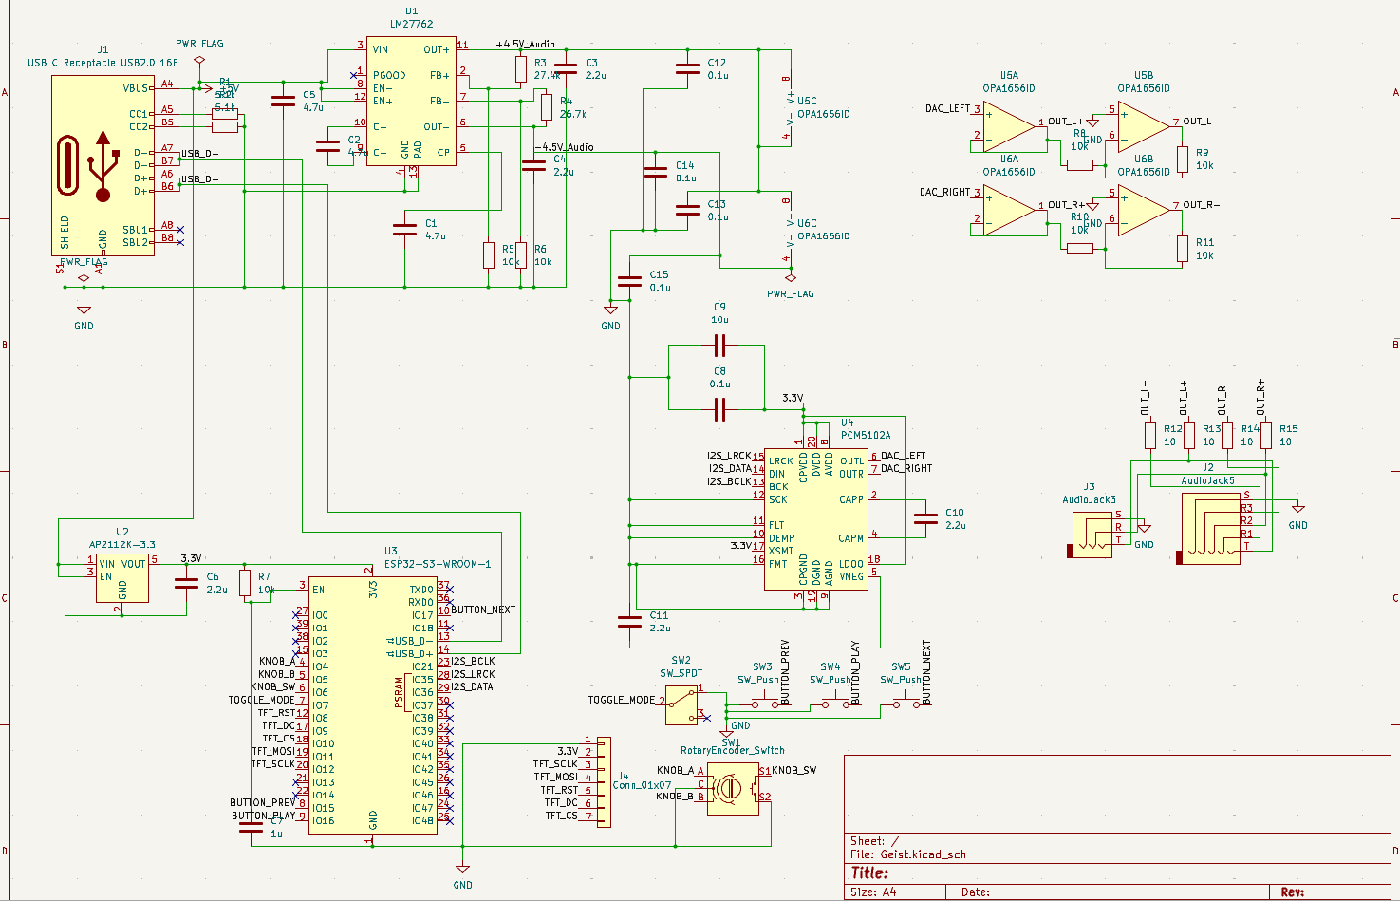
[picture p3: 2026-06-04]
Screenshot 2026-05-27 231549.png

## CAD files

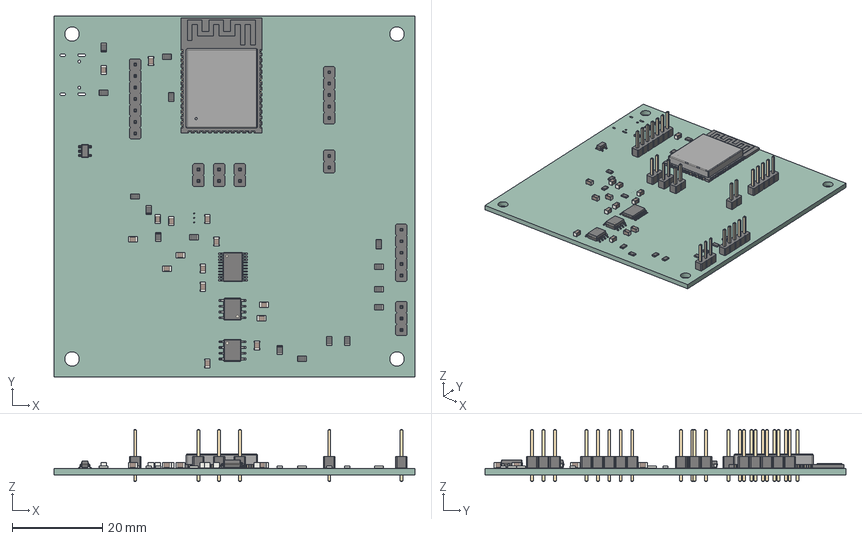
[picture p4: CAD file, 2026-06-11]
Geist_Mech.step
80.0 x 80.0 x 11.5 mm
PinHeader_1x02_P2.54mm_Vertical x 4
R_0805_2012Metric x 16
C_0805_2012Metric x 15
PinHeader_1x07_P2.54mm_Vertical
PinHeader_1x05_P2.54mm_Vertical x 2
SOIC-8_3.9x4.9mm_P1.27mm x 2
SOT-23-5
PinHeader_1x03_P2.54mm_Vertical
TSSOP-20_4.4x6.5mm_P0.65mm
ESP32-S3-WROOM-1
Geist_PCB

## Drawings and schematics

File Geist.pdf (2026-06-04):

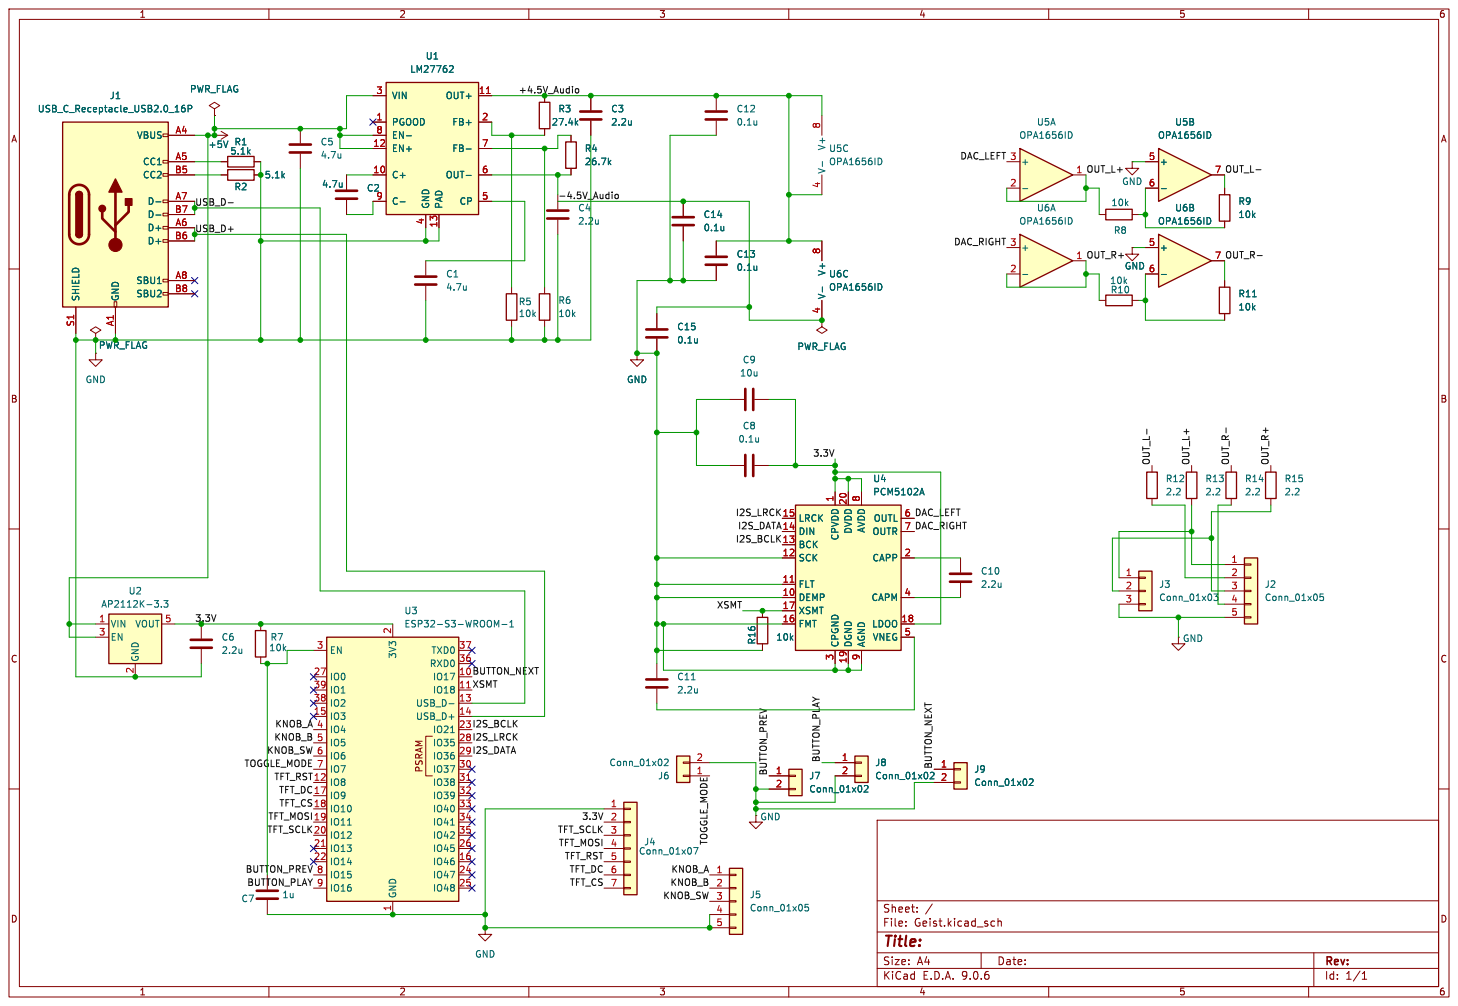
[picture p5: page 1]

4 PAD 13 OUT+ 11 FB+ 2 FB- 7 OUT- 6 CP 5 U1

4 PAD 13 OUT+ 11 FB+ 2 FB- 7 OUT- 6 CP 5 C2 4.7u

9 OUTL 6 OUTR 7 CAPP 2 CAPM 4

Id: 1/1 Title: File: Geist.kicad_sch Sheet: /

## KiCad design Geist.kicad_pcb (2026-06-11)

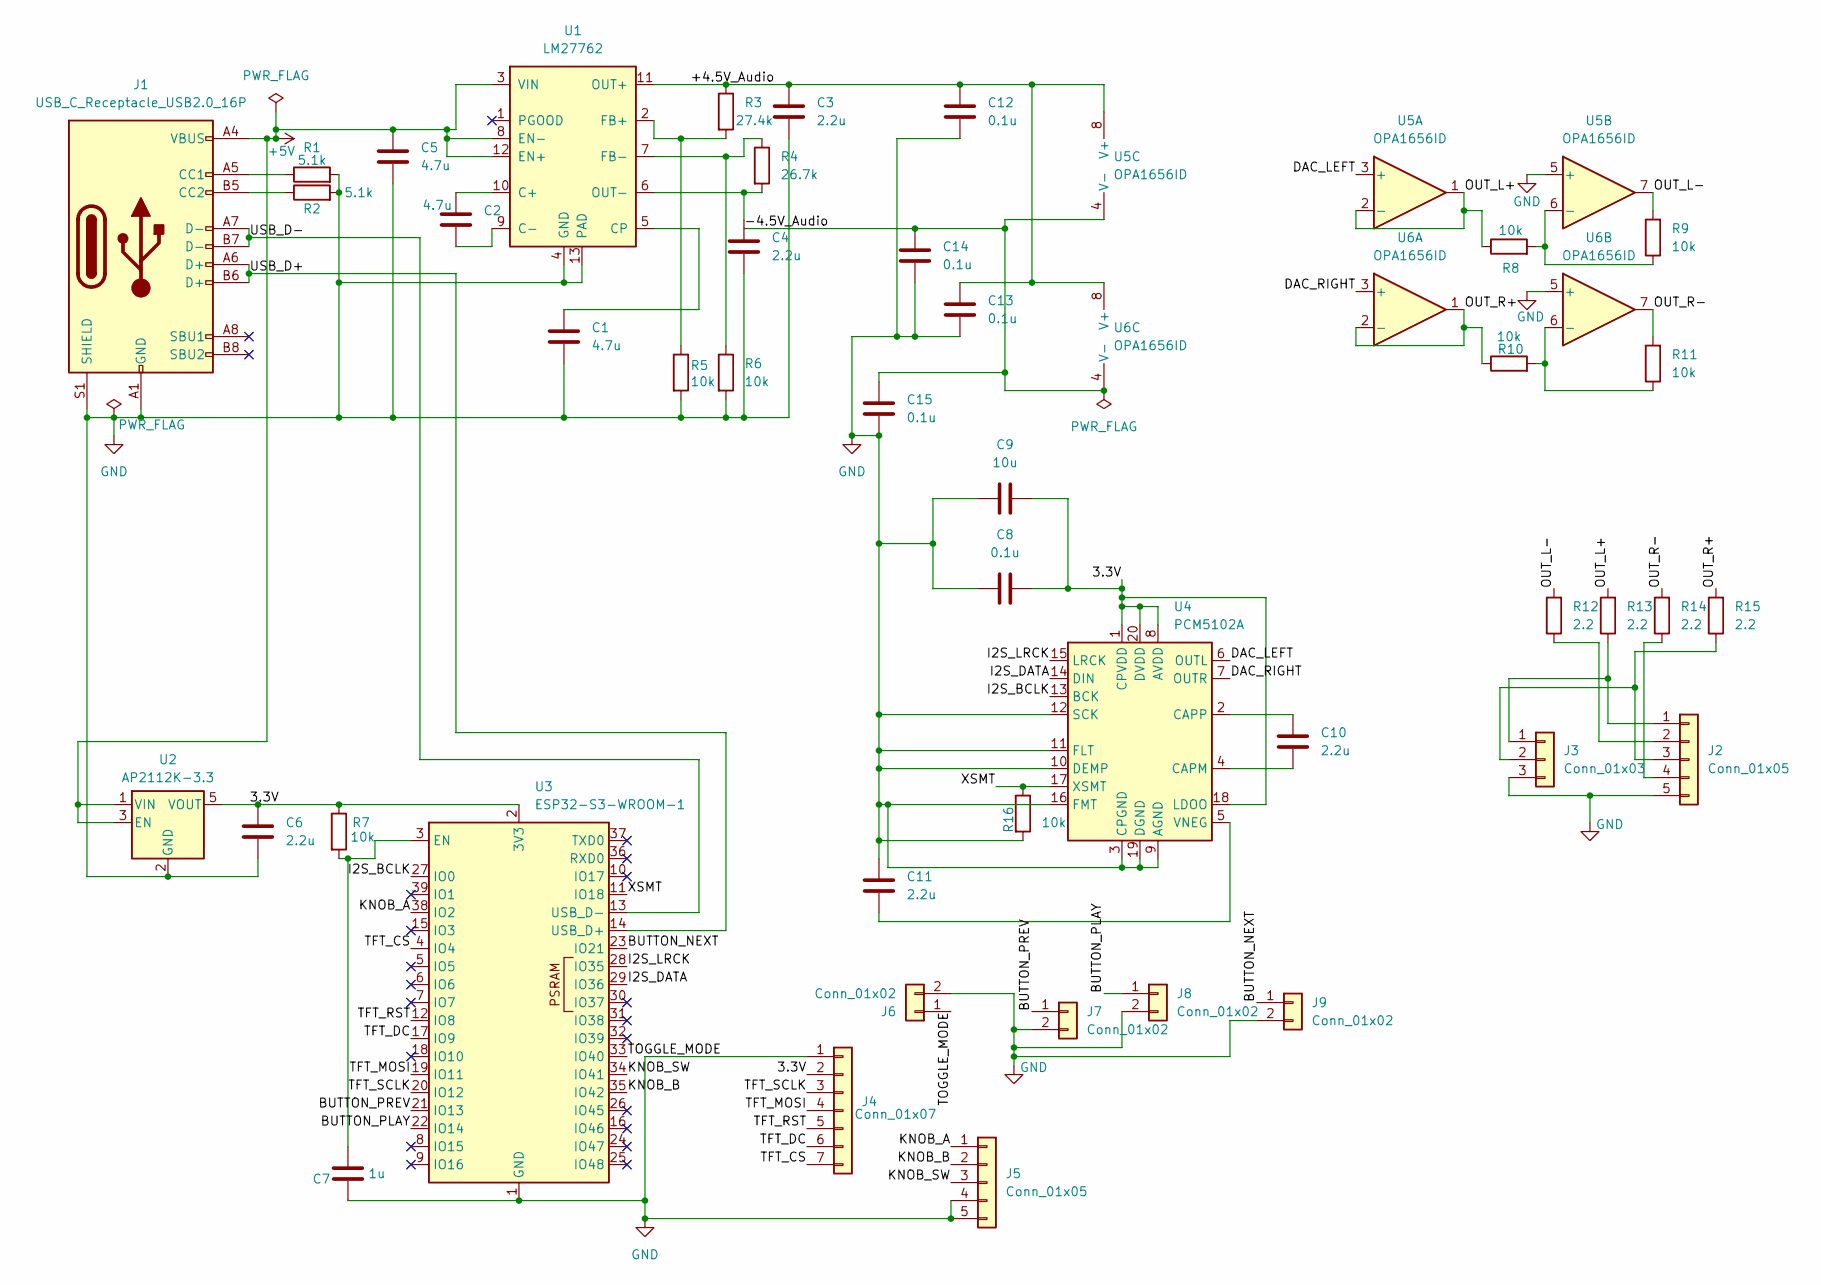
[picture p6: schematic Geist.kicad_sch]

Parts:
C1, C2, C5: 4.7u; C_0805_2012Metric_Pad1.18x1.45mm_HandSolder
C3, C4, C6, C10, C11: 2.2u; C_0805_2012Metric_Pad1.18x1.45mm_HandSolder
C7: 1u; C_0805_2012Metric_Pad1.18x1.45mm_HandSolder
C8, C12, C13, C14, C15: 0.1u; C_0805_2012Metric_Pad1.18x1.45mm_HandSolder
C9: 10u; C_0805_2012Metric_Pad1.18x1.45mm_HandSolder
J1: USB_C_Receptacle_USB2.0_16P; USB_C_Receptacle_HRO_TYPE-C-31-M-12
J2, J5: Conn_01x05; PinHeader_1x05_P2.54mm_Vertical
J3: Conn_01x03; PinHeader_1x03_P2.54mm_Vertical
J4: Conn_01x07; PinHeader_1x07_P2.54mm_Vertical
J6, J7, J8, J9: Conn_01x02; PinHeader_1x02_P2.54mm_Vertical
R1, R2: 5.1k; R_0805_2012Metric_Pad1.20x1.40mm_HandSolder
R3: 27.4k; R_0805_2012Metric_Pad1.20x1.40mm_HandSolder
R4: 26.7k; R_0805_2012Metric_Pad1.20x1.40mm_HandSolder
R5, R6, R7, R8, R9, R10, R11, R16: 10k; R_0805_2012Metric_Pad1.20x1.40mm_HandSolder
R12, R13, R14, R15: 2.2; R_0805_2012Metric_Pad1.20x1.40mm_HandSolder
U1: LM27762; WSON-12-1EP_3x2mm_P0.5mm_EP1x2.65_ThermalVias
U2: AP2112K-3.3; SOT-23-5
U3: ESP32-S3-WROOM-1
U4: PCM5102A; TSSOP-20_4.4x6.5mm_P0.65mm
U5, U6: OPA1656ID; SOIC-8_3.9x4.9mm_P1.27mm

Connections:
+5V: C5.1, J1.A4 (VBUS), J1.A9 (VBUS), J1.B4 (VBUS), J1.B9 (VBUS), U1.3 (VIN), U1.8 (EN-), U1.12 (EN+), U2.1 (VIN), U2.3 (EN)
/3.3V: C6.1, C8.2, C9.2, J4.2, R7.1, U2.5 (VOUT), U3.2 (3V3), U4.1 (CPVDD), U4.8 (AVDD), U4.18 (LDOO), U4.20 (DVDD)
/+4.5V_Audio: C3.1, C12.2, C13.2, R3.1, U1.11 (OUT+), U5.8 (V+), U6.8 (V+)
/-4.5V_Audio: C14.2, C15.2, U5.4 (V-), U6.4 (V-)
/BUTTON_NEXT: J9.1, U3.23 (IO21)
/BUTTON_PLAY: J8.1, U3.22 (IO14)
/BUTTON_PREV: J7.1, U3.21 (IO13)
/DAC_LEFT: U4.6 (OUTL), U5.3 (+)
/DAC_RIGHT: U4.7 (OUTR), U6.3 (+)
/I2S_BCLK: U3.27 (IO0), U4.13 (BCK)
/I2S_DATA: U3.29 (IO36), U4.14 (DIN)
/I2S_LRCK: U3.28 (IO35), U4.15 (LRCK)
/KNOB_A: J5.1, U3.38 (IO2)
/KNOB_B: J5.2, U3.35 (IO42)
/KNOB_SW: J5.3, U3.34 (IO41)
/OUT_L+: R8.1, R13.2, U5.1, U5.2 (-)
/OUT_L-: R9.2, R12.2, U5.7
/OUT_R+: R10.1, R15.2, U6.1, U6.2 (-)
/OUT_R-: R11.2, R14.2, U6.7
/TFT_CS: J4.7, U3.4 (IO4)
/TFT_DC: J4.6, U3.17 (IO9)
/TFT_MOSI: J4.4, U3.19 (IO11)
/TFT_RST: J4.5, U3.12 (IO8)
/TFT_SCLK: J4.3, U3.20 (IO12)
/TOGGLE_MODE: J6.1, U3.33 (IO40)
/USB_D+: J1.A6 (D+), J1.B6 (D+), U3.14 (USB_D+)
/USB_D-: J1.A7 (D-), J1.B7 (D-), U3.13 (USB_D-)
/XSMT: R16.1, U3.11 (IO18), U4.17 (XSMT)
GND: C1.2, C3.2, C4.2, C5.2, C6.2, C7.2, C8.1, C9.1, C11.2, C12.1, C13.1, C14.1, C15.1, J1.A1 (GND), J1.A12 (GND), J1.B1 (GND), J1.B12 (GND), J1.S1 (SHIELD), J2.5, J3.3, J4.1, J5.4, J5.5, J6.2, J7.2, J8.2, J9.2, R1.2, R2.2, R5.2, R6.2, R16.2, U1.4 (GND), U1.13 (PAD), U2.2 (GND), U3.1 (GND), U3.40 (GND), U3.41 (GND), U4.3 (CPGND), U4.9 (AGND), U4.10 (DEMP), U4.11 (FLT), U4.12 (SCK), U4.16 (FMT), U4.19 (DGND), U5.5 (+), U6.5 (+)
unnamed: J1.A5 (CC1), R1.1
unnamed: J1.B5 (CC2), R2.1
unnamed: J2.1, J3.1, R13.1
unnamed: J2.2, R12.1
unnamed: J2.3, J3.2, R15.1
unnamed: J2.4, R14.1
unnamed: C2.1, U1.10 (C+)
unnamed: C2.2, U1.9 (C-)
unnamed: C1.1, U1.5 (CP)
unnamed: R3.2, R5.1, U1.2 (FB+)
unnamed: R4.1, R6.1, U1.7 (FB-)
unnamed: C4.1, R4.2, U1.6 (OUT-)
unnamed: C7.1, R7.2, U3.3 (EN)
unnamed: C10.1, U4.4 (CAPM)
unnamed: C10.2, U4.2 (CAPP)
unnamed: C11.1, U4.5 (VNEG)
unnamed: R8.2, R9.1, U5.6 (-)
unnamed: R10.2, R11.1, U6.6 (-)

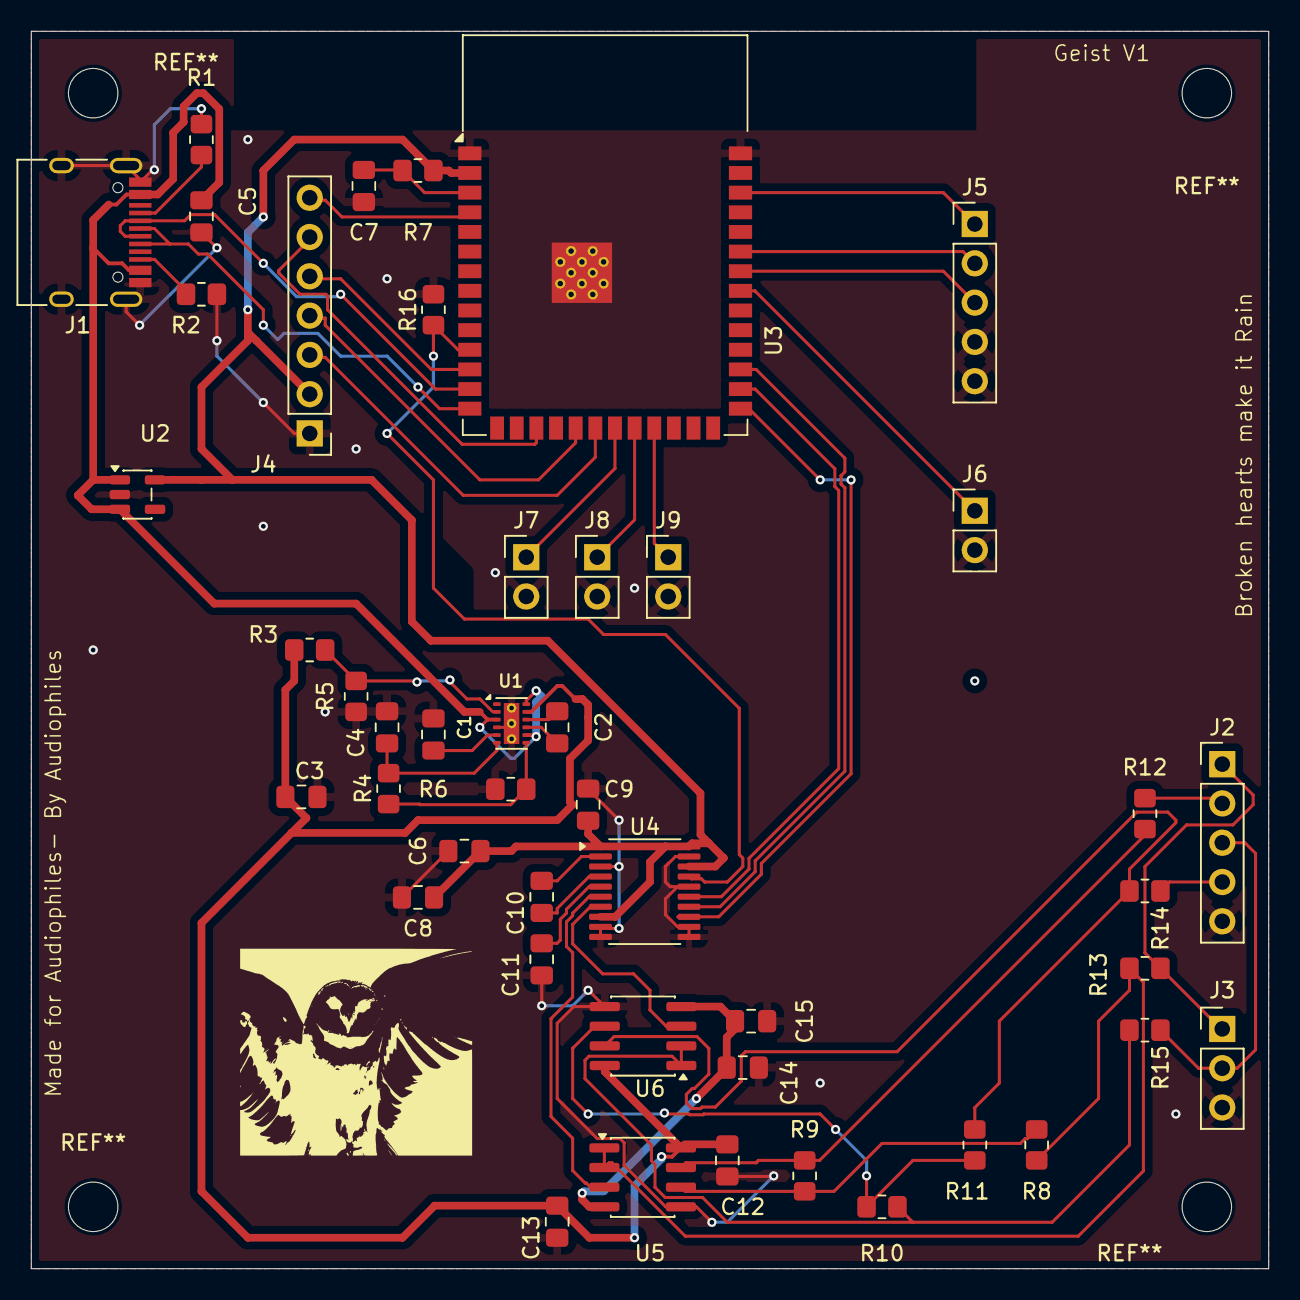
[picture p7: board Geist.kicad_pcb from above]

Board: 2 copper layers, 80.0 x 80.0 mm, 46 parts (0 on the bottom side), 47 nets.

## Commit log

2026-06-05 GND pour
    laid gnd pour on the pcb and adjusted some pins to suit better routing. Will work on chopping down DRC next.
    [Geist.kicad_pcb, Geist.kicad_sch]
2026-06-06 DRC fixes
    further rectified DRC errors, now just need to add vias to thermal relief pads
    [Geist.kicad_pcb]
2026-06-06 Adding reference pic for pcb
    adding a picture of almost-finished pcb design for future reference in case of changes.
2026-06-08 PCB Finished
    FIxed all DRCs and made further design decisions like making usb c connector hang 1mm off the edge. Added mounting holes. PCB finished. Will add bitmap in next commit.
    [Geist.kicad_pcb, Geist.kicad_sch]
2026-06-11 Started enclosure +electric_to_air
    started making enclosure in fusion 360 and board is fully finalised and rechecked multiple times. Added electric_to_air markdown file to explain the whole process start to finish.
    [Geist.kicad_pcb, Geist_Mech.step]
